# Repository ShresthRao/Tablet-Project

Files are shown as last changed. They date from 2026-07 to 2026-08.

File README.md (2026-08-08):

# Tablet Project
## Description
This project is a custom tablet. It contains a custom PCB and case. The PCB connects to a CM4 Lite Wireless module for processing and wireless connections. The PCB is connected to a Viekk VK1200 V2 device that is used as the digitiser, stylus and the display.

## Bill of Materials (BOM)

* Note: All prices are in USD (inclusive of GST where applicable). Production and assembly files contain additional specs where applicable.
* Note: Bom for Item 4: JLCPCB Custom Manufactured PCB is in /Production/assembly/Custom Tablet_bom_raw.csv, /Production/assembly/Custom Tablet_jlcpcb_bom.csv

### Purchased Components

| Item | Qty | Component | Price/1 Item (USD) | Link | Description |
| :---: | :---: | :--- | :---: | :--- | :--- |
| 1 | 2 | NOVA 9060100 8000mAh 3.7V Micro LiPo Battery Pack with PCB & 100mm Cable | $9.34 | [Robu.in](https://robu.in/product/nova-9060100-8000mah-3-7v-lipo-battery-pack/) | Lined in Parallel |
| 2 | 4 | Harwin R25-1001102 Hex Standoffs | $0.51 | [Element14](https://in.element14.com/harwin/r25-1001102/standoff-hex-f-f-brass-m2-5-11mm/dp/3754478) | Standoffs for CM4 module |
| 3 | 1 | Raspberry Pi Compute Module 4 | $110.16 | [Element14](https://in.element14.com/raspberry-pi/cm4104000/rpi-compute-module-4-lite-4gb/dp/3563487) | Compute module |
| 4 | 1 | JLCPCB Custom Manufactured PCB | $279.95 | [JLCPCB](https://cart.jlcpcb.com/quote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) | Custom PCB Ordered through JLCPCB |
| 5 | 1 | VEIKK VK1200 V2 Drawing Tablet | $157.65 | [Amazon](https://www.amazon.in/gp/product/B08G8CKSWK/) | Acts as the Screen, Digitiser and Stylus |
| 6 | 1 | Heat Shrink Tubing Kit (328 pcs) | $1.64 | [Robu.in](https://robu.in/product/328pcs-heat-shrink-tube-heat-shrink-tube-kit/) | Protection against short circuits |
| 7 | 1 | High-Temperature Kapton Polyimide Tape (10mm × 33m) | $1.03 | [Robu.in](https://robu.in/product/10mm-33m-100ft-high-temperature-heat-resistant-polyimide-kapton-tape-hot/) | Insulation |
| 8 | 1 | Digital Multimeter (Small LCD, AC/DC) | $1.80 | [Robu.in](https://robu.in/product/digital-multimeter-small-yellow-color-lcd-ac-dc-measuring-voltage-current/) | Tool to check for battery voltage and proper functionality |
| 9 | 1 | Multimeter Test Probes | $1.25 | [Robu.in](https://robu.in/product/1-month-warranty-1260/) | Probes for multimeter |
| Total | | | $575 (Adjusted for future price changes) | | |

### On-Hand Hardware & Tools

* Storage: Micro-SD card (64GB+)
* Cables: 3x USB-C cables, 1x Short HDMI cable
* Wiring: Red and Black battery wire
* Tools & Consumables: Soldering iron, flux, solder, tweezers, superglue
* Peripherals: USB keyboard and mouse

## Specifications
### Screen:
11.6 inch
Laminated anti-glare
8,192 levels of pressure sensitivity
Resolution is 1920 × 1080 pixels (Full HD)
Color Gamut: 72% NTSC

### PCB
1 HDMI port for connection of VIEKK VK1200 V2 device.
1 SD card slot
2 USB-C ports
2 Connectors for CM4 Lite Wireless module
1 Solder pads for connection of batteries

### Stylus
2 battery-less styluses
8,192 levels of pressure
60 degrees of tilt
290 RPS of report rate
5080 LPI of resolution

### Case (total size of custom tablet)
202 mm width
378 mm length
24 mm tall

### Software
Raspberry Pi OS (64-bit) with VIEKK drivers

## Screenshots of the design:
### Schematic
#### Full Screenshot
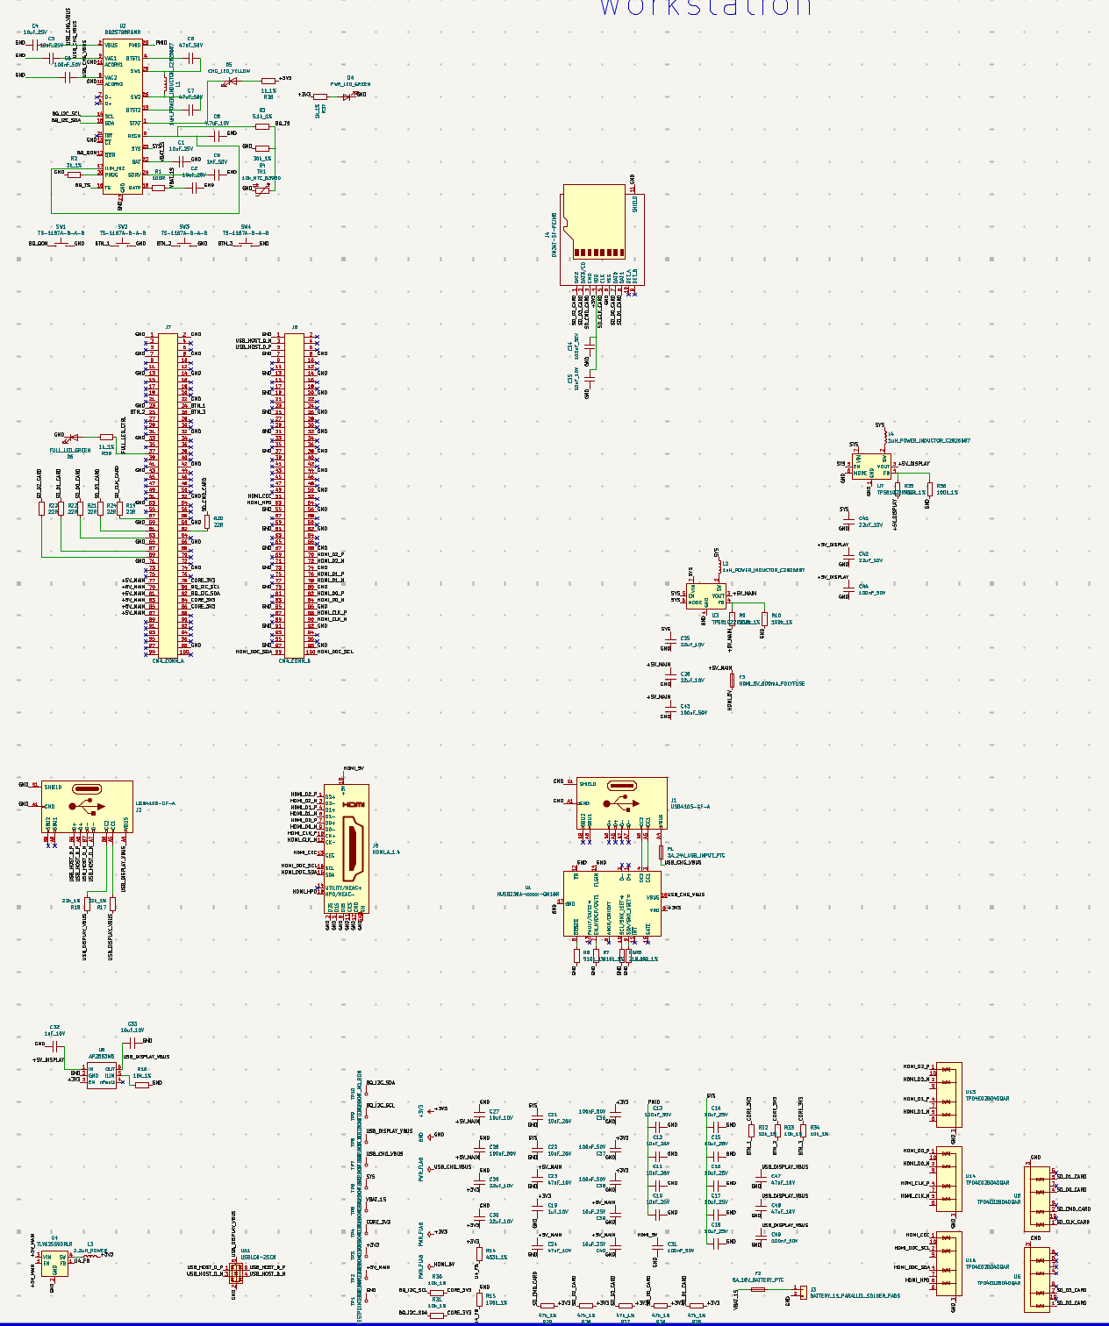
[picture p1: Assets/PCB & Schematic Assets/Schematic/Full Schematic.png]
Full Schematic Overview


#### Part-Wise screenshots
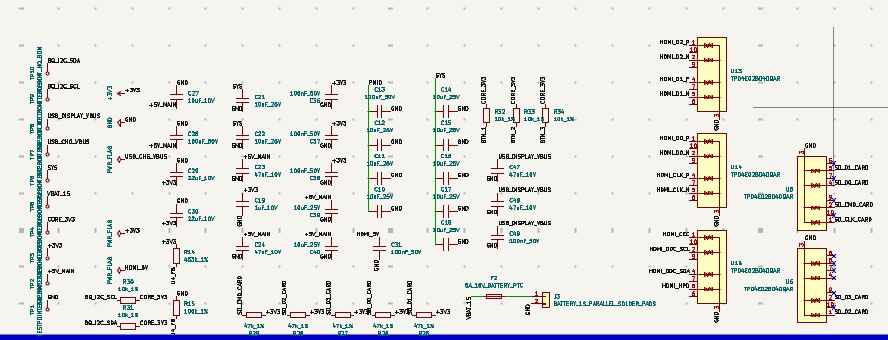
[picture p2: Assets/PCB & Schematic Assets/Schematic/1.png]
Schematic Page 1

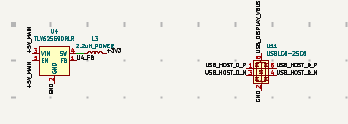
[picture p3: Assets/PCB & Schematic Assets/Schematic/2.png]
Schematic Page 2

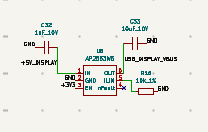
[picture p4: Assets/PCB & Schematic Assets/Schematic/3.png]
Schematic Page 3

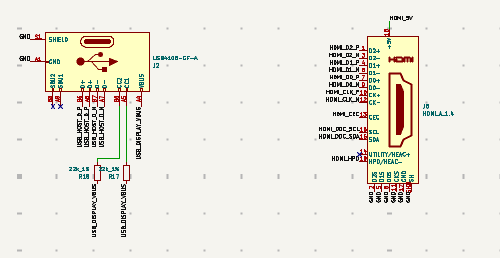
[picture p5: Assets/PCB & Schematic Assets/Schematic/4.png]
Schematic Page 4

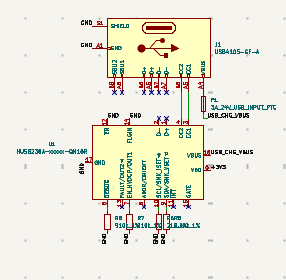
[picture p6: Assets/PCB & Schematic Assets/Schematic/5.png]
Schematic Page 5

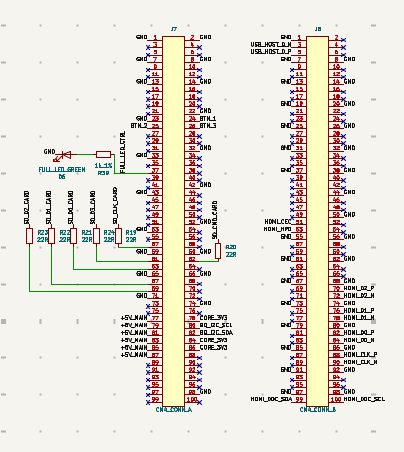
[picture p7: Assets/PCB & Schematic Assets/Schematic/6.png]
Schematic Page 6

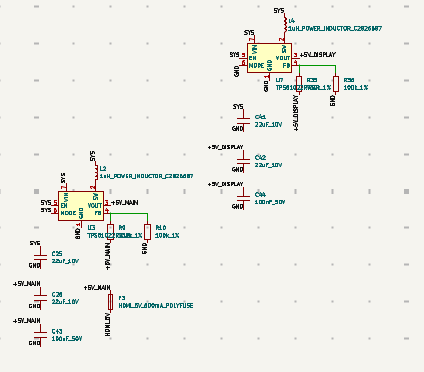
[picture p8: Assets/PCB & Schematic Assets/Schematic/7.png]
Schematic Page 7

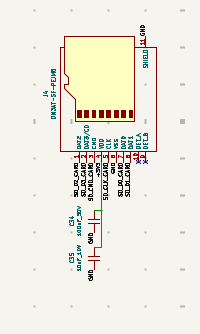
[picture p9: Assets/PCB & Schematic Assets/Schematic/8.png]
Schematic Page 8

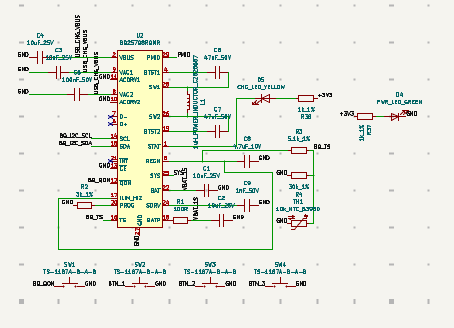
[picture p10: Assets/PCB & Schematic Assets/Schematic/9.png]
Schematic Page 9


### PCB
#### Zoned
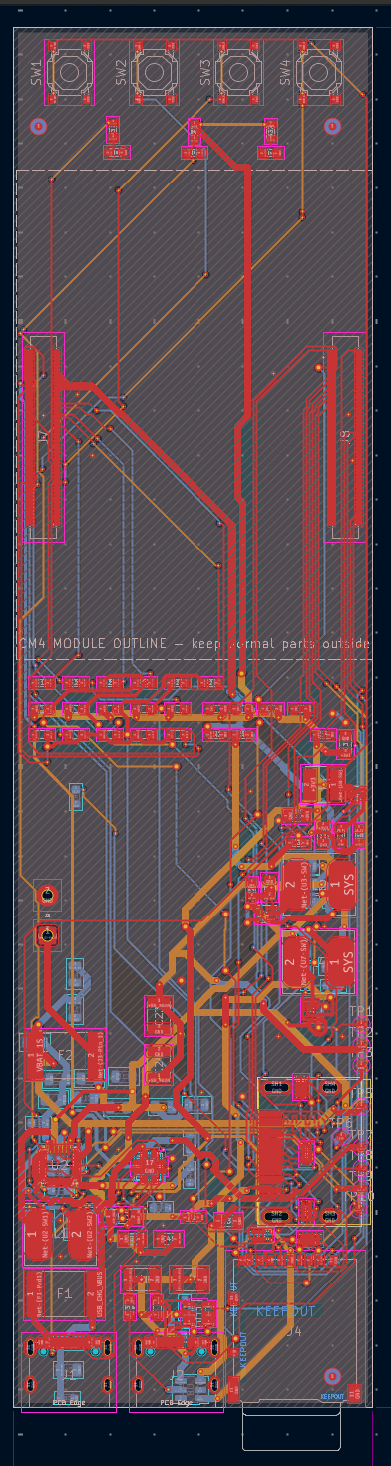
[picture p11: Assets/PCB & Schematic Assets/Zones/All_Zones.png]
All Layers With Zones

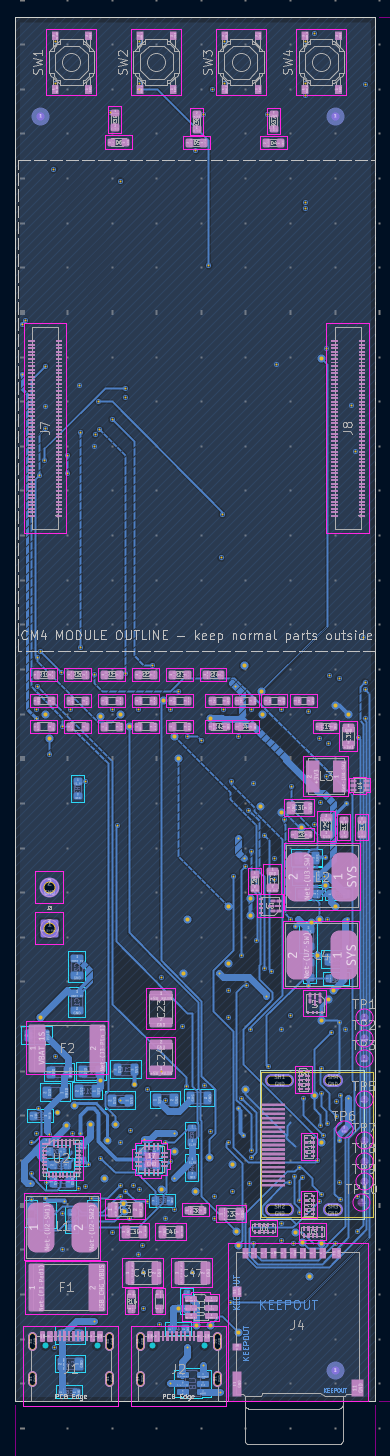
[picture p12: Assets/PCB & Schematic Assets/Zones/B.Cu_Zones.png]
Bottom Copper With Zones

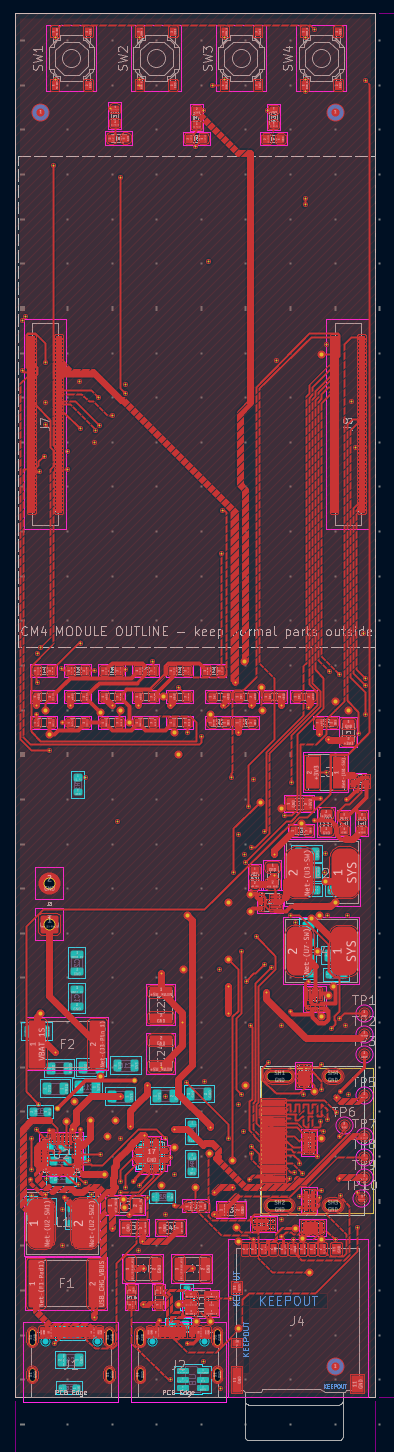
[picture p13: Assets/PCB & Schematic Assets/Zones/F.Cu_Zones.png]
Front Copper With Zones

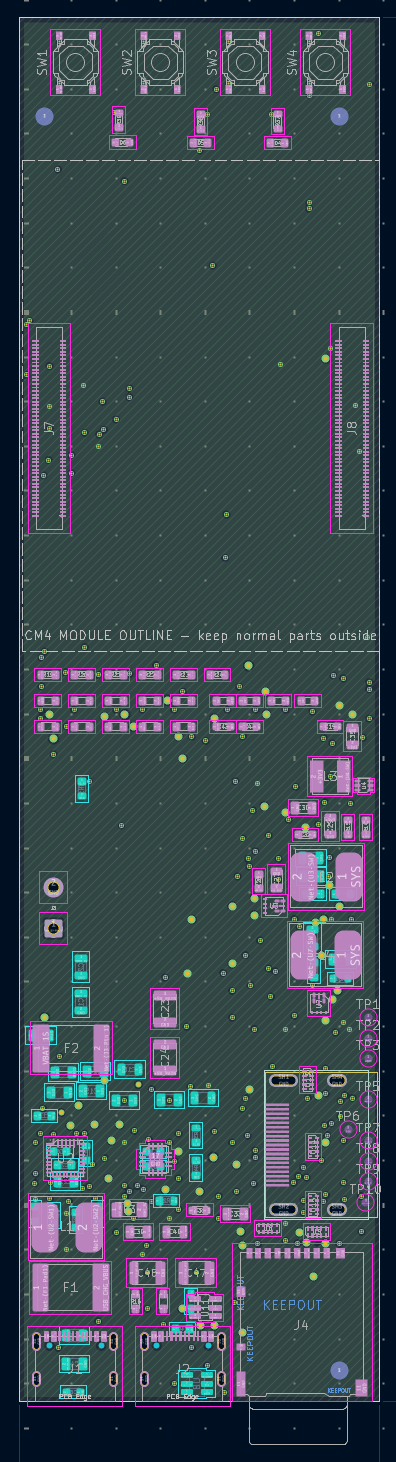
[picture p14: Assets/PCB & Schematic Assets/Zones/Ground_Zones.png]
Ground Copper With Zones

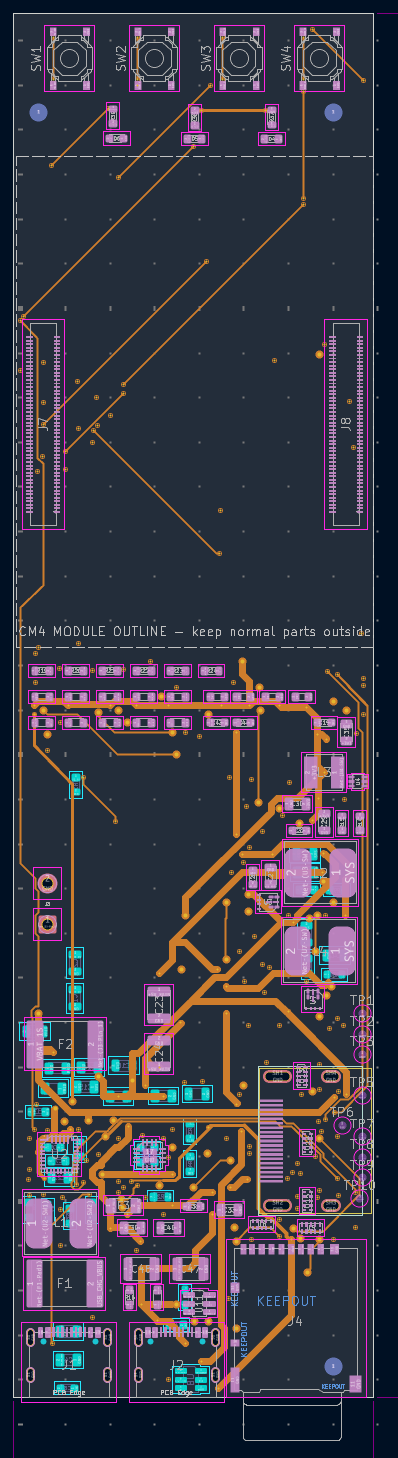
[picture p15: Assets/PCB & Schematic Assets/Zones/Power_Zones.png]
Power Copper With Zones


#### Un-Zoned
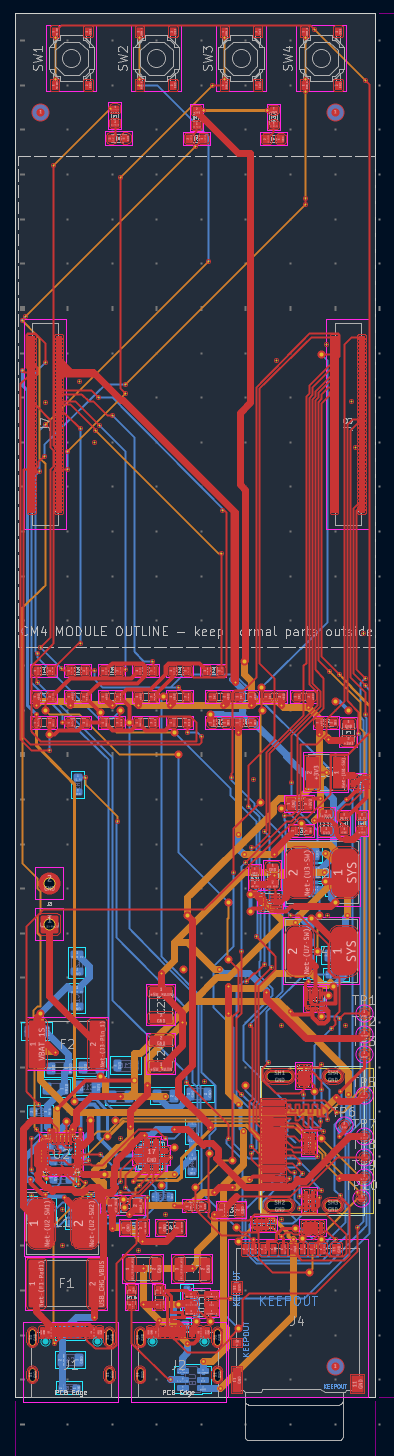
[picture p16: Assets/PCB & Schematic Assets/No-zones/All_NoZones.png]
All Layers No Zones

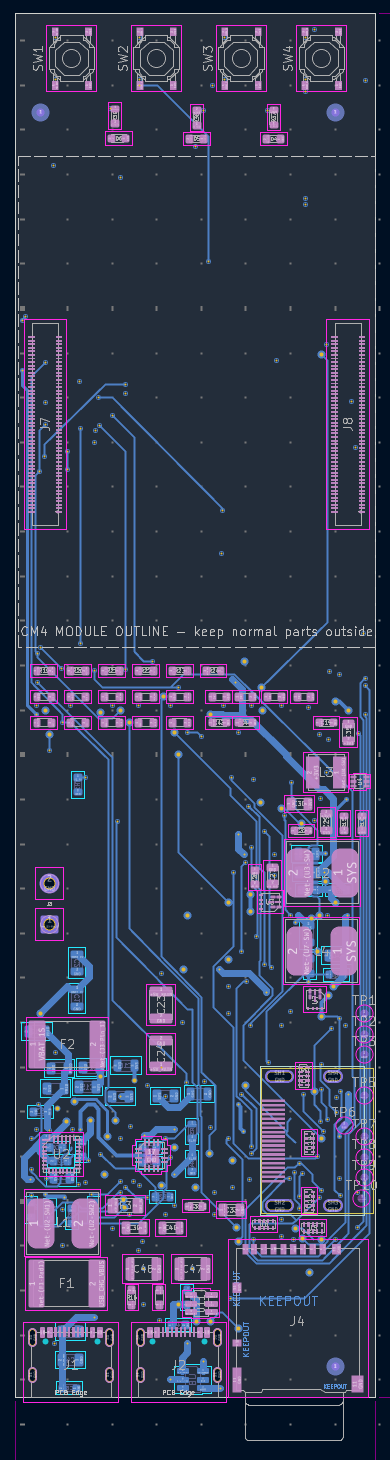
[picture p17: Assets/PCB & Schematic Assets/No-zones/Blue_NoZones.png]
Blue Layer No Zones

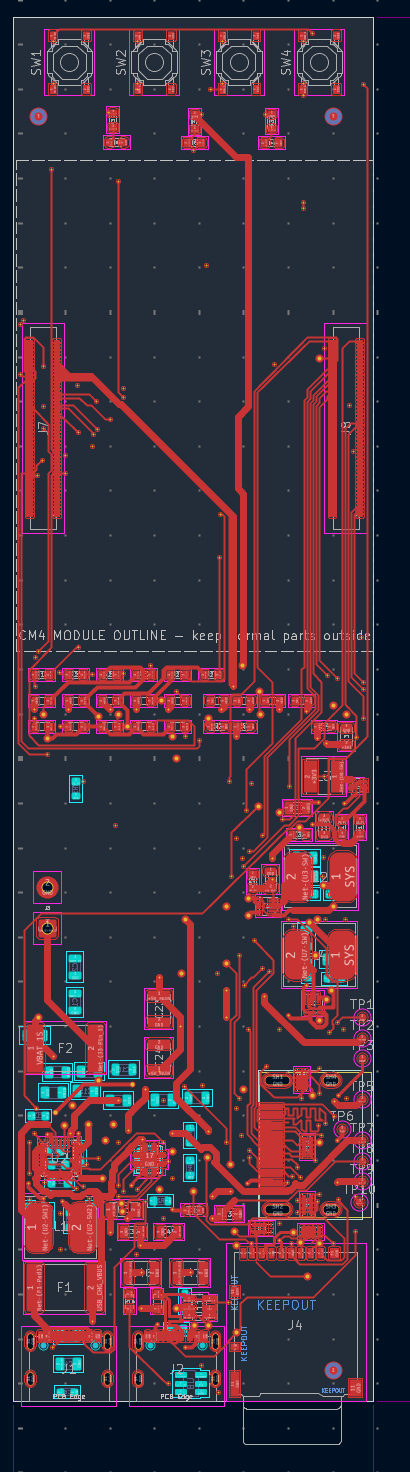
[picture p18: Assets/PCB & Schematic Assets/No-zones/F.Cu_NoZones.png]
Front Copper No Zones

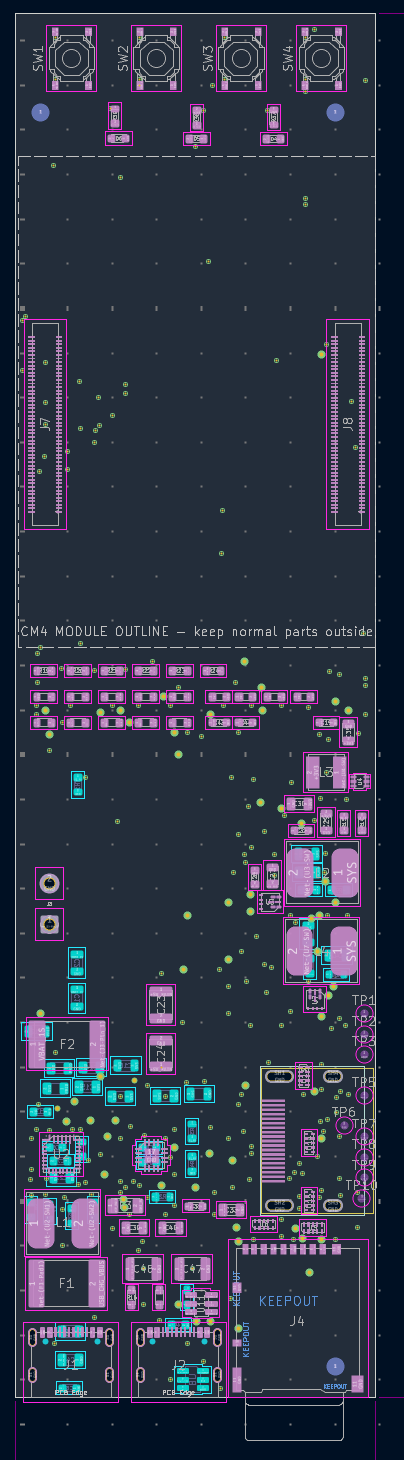
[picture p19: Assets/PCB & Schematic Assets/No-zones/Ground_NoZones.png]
Ground Layer No Zones

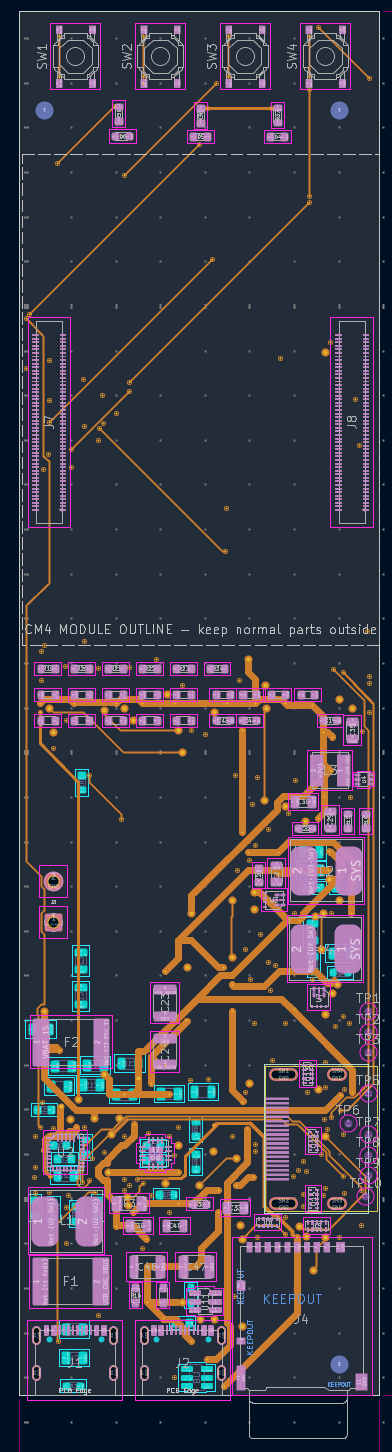
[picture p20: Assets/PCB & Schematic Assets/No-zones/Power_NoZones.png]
Power Layer No Zones


### CAD
#### Assembly
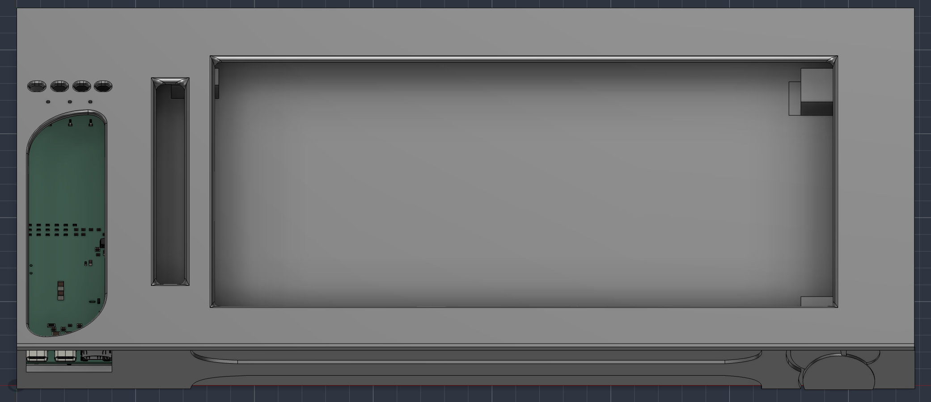
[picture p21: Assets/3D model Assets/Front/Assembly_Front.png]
Assembly Front View


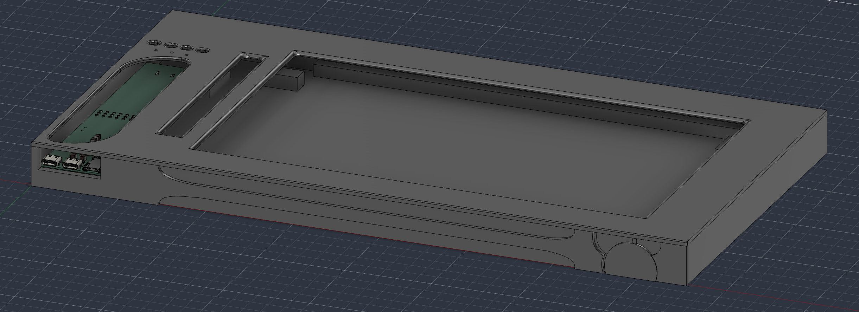
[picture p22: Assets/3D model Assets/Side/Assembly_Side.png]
Assembly Side View


#### Bottom Case
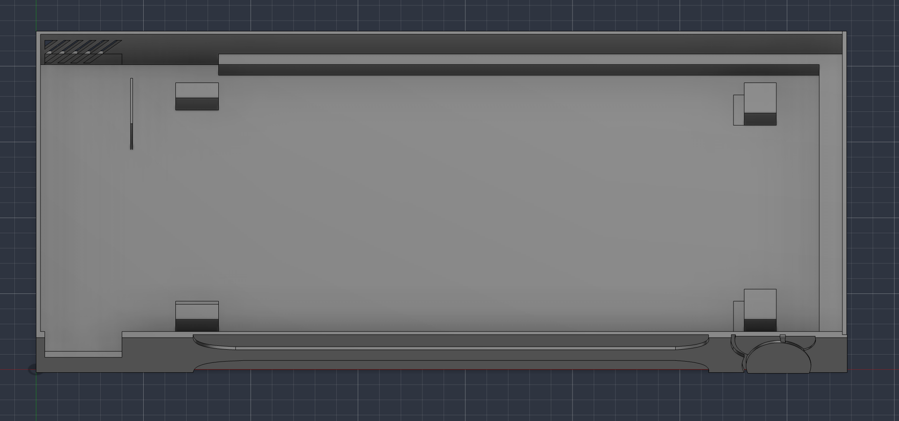
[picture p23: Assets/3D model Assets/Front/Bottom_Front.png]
Bottom Front View


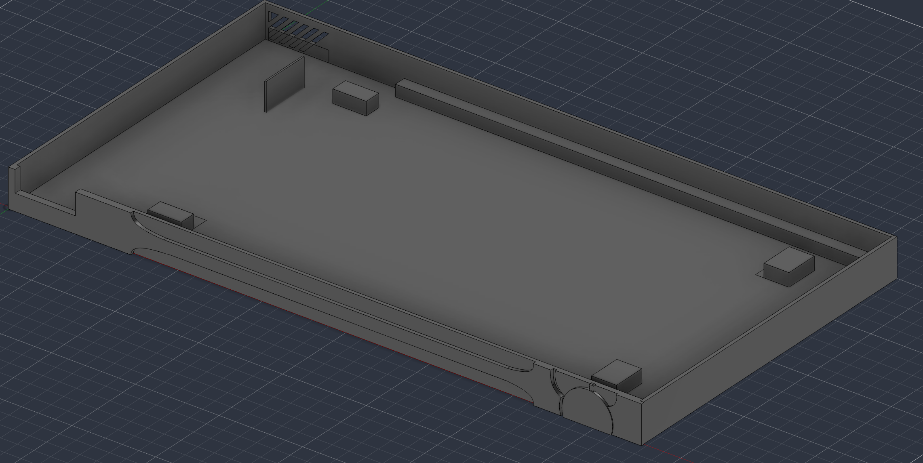
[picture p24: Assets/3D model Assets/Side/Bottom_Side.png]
Bottom Side View


#### Top Case
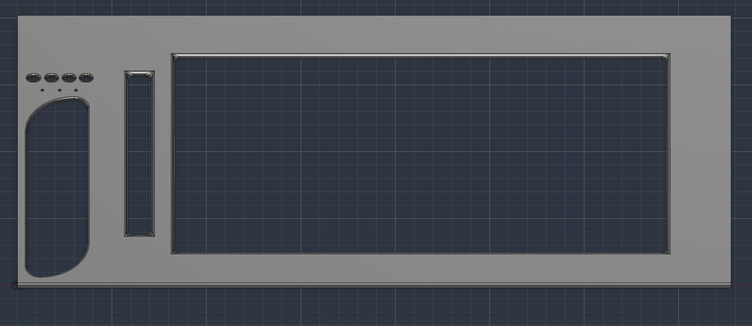
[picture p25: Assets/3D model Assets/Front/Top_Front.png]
Top Front View


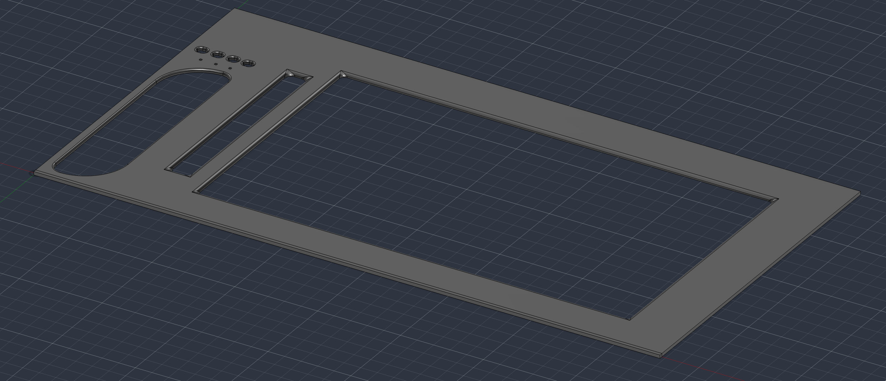
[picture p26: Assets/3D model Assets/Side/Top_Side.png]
Top Side View


****

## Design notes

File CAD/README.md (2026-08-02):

# CAD Files
## 3D print:stl files
These files are only for 3D printing, consisting of files for the top and bottom case. Any changes to source files would mean that these stl files need to be exported again.
## Assembly
These files are the assembly file in two formats (.f3z/.f3d and .step). It is a file consisting of the top case, bottom case and 3D PCB model all put together.
## Source files
### Bottom_Case
These files are the files related to the bottom case 3D model in two formats (.f3z and .step) and are used to edit the 3D model yourself.
### PCB_3D model
These files are the files related to the PCB 3D model in two formats (.f3z and .step) and are used to edit the 3D model yourself.
### Top_Case
These files are the files related to the top case 3D model in two formats (.f3z and .step) and are used to edit the 3D model yourself.

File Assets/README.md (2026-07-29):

# Asset Files
## 3D model files
### Front
These files are the screenshots of how the front view of the Assembly, Bottom Case and Top Case look.
### Side
These files are the screenshots of how the side view of the Assembly, Bottom Case and Top Case look.

## PCB & Schematic Assets
### No-Zones
These files are the screenshots of how all four planes individually look without any zones and how they look all together when combined.
### Schematic
These files are the screenshots of all components in the schematic.
### Zones
These files are the screenshots of how all four planes individually look with zones and how they look all together when combined.

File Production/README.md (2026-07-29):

# Production Files
## Assembly
This folder contains a file including all the positions of components on the PCB, in case any manufacturer requires such a file (Custom Tablet_positions.csv). 
It also includes the file used as a bill of materials for all the components JLCPCB will source (Custom Tablet_jlcpcb_bom.csv). 
It also contains a raw bill of materials file that is used for personal reference of all parts (not just JLCPCB sourced parts) (Custom Tablet_bom_raw.csv).
## Checks
This folder contains the final ERC and DRC checks to ensure that the PCB does not have any fatal errors before production. If PCB files are altered, they must be exported again.
## Gerbers
This folder contains all the files most manufacturers will need to manufacture the pcb. This includes drill files and all the other files necessary.

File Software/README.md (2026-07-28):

# Software:
## Steps:
### Download the Raspberry Pi OS (64-bit) model:

Link--> https://www.raspberrypi.com/software/operating-systems/

Scroll down to the Raspberry Pi OS (64-bit) and press download button next to "Raspberry Pi OS"

### Uploading the OS to tablet:

Download Raspberry Pi Imager

Attach SD card that is going to be used for the Tablet (Min 64gb)

Open app and select downloaded OS file and write to the attached SD card.

When finished, disconnect the SD card.

Then, connect the SD card to the Tablet and power on.

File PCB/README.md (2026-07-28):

# PCB Files
These are the files that are used to make your own changes to the PCB.
They are files for personal use, not for production

## Main files
Base files to open in KiCad

## Custom Libraries and 3D models
Files to import into KiCad as Footrprints and Symbols for specific parts of the PCB.

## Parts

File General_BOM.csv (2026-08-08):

Section | Item | Qty | Component | Price/1 Item (USD) | Link | Description
Note |  |  | All prices are in USD (inclusive of GST where applicable). Production and assembly files contain additional specs where applicable.
Note |  |  | Bom for Item 4: JLCPCB Custom Manufactured PCB is in /Production/assembly/Custom Tablet_bom_raw.csv, /Production/assembly/Custom Tablet_jlcpcb_bom.csv
Purchased Components | 1 | 2 | NOVA 9060100 8000mAh 3.7V Micro LiPo Battery Pack with PCB & 100mm Cable | $9.34 | https://robu.in/product/nova-9060100-8000mah-3-7v-lipo-battery-pack/ | Lined in Parallel
Purchased Components | 2 | 4 | Harwin R25-1001102 Hex Standoffs | $0.51 | https://in.element14.com/harwin/r25-1001102/standoff-hex-f-f-brass-m2-5-11mm/dp/3754478 | Standoffs for CM4 module
Purchased Components | 3 | 1 | Raspberry Pi Compute Module 4 | $110.16 | https://in.element14.com/raspberry-pi/cm4104000/rpi-compute-module-4-lite-4gb/dp/3563487 | Compute module
Purchased Components | 4 | 1 | JLCPCB Custom Manufactured PCB | $279.95 | https://cart.jlcpcb.com/quote | Custom PCB Ordered through JLCPCB
Purchased Components | 5 | 1 | VEIKK VK1200 V2 Drawing Tablet | $157.65 | https://www.amazon.in/gp/product/B08G8CKSWK/ | Acts as the Screen, Digitiser and Stylus
Purchased Components | 6 | 1 | Heat Shrink Tubing Kit (328 pcs) | $1.64 | https://robu.in/product/328pcs-heat-shrink-tube-heat-shrink-tube-kit/ | Protection against short circuits
Purchased Components | 7 | 1 | High-Temperature Kapton Polyimide Tape (10mm × 33m) | $1.03 | https://robu.in/product/10mm-33m-100ft-high-temperature-heat-resistant-polyimide-kapton-tape-hot/ | Insulation
Purchased Components | 8 | 1 | Digital Multimeter (Small LCD, AC/DC) | $1.80 | https://robu.in/product/digital-multimeter-small-yellow-color-lcd-ac-dc-measuring-voltage-current/ | Tool to check for battery voltage and proper functionality
Purchased Components | 9 | 1 | Multimeter Test Probes | $1.25 | https://robu.in/product/1-month-warranty-1260/ | Probes for multimeter
Purchased Components | Total |  |  | $575 (Adjusted for future price changes)
On-Hand Hardware & Tools |  |  | Storage: Micro-SD card (64GB+)
On-Hand Hardware & Tools |  |  | Cables: 3x USB-C cables, 1x Short HDMI cable
On-Hand Hardware & Tools |  |  | Wiring: Red and Black battery wire
On-Hand Hardware & Tools |  |  | Tools & Consumables: Soldering iron, flux, solder, tweezers, superglue
On-Hand Hardware & Tools |  |  | Peripherals: USB keyboard and mouse

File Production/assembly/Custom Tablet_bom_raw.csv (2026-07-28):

Designator | Comment | Footprint | LCSC | MPN | Manufacturer | Datasheet | Description | Quantity
C1 | 10uF_25V | Capacitor_SMD:C_0805_2012Metric | C15850 | CL21A106KAYNNNE | Samsung Electro-Mechanics |  | Unpolarized capacitor | 1
C2 | 10uF_25V | Capacitor_SMD:C_0805_2012Metric | C15850 | CL21A106KAYNNNE | Samsung Electro-Mechanics |  | Unpolarized capacitor | 1
C3 | 10uF_25V | Capacitor_SMD:C_0805_2012Metric | C15850 | CL21A106KAYNNNE | Samsung Electro-Mechanics |  | Unpolarized capacitor | 1
C4 | 10uF_25V | Capacitor_SMD:C_0805_2012Metric | C15850 | CL21A106KAYNNNE | Samsung Electro-Mechanics |  | Unpolarized capacitor | 1
C5 | 100nF_50V | Capacitor_SMD:C_0603_1608Metric | C14663 | CC0603KRX7R9BB104 | YAGEO |  | Unpolarized capacitor | 1
C6 | 47nF_50V | Capacitor_SMD:C_0603_1608Metric | C1622 | CL10B473KB8NNNC | Samsung Electro-Mechanics |  | Unpolarized capacitor | 1
C7 | 47nF_50V | Capacitor_SMD:C_0603_1608Metric | C1622 | CL10B473KB8NNNC | Samsung Electro-Mechanics |  | Unpolarized capacitor | 1
C8 | 4.7uF_10V | Capacitor_SMD:C_0603_1608Metric | C19666 | CL10A475KO8NNNC | Samsung Electro-Mechanics |  | Unpolarized capacitor | 1
C9 | 1nF_50V | Capacitor_SMD:C_0603_1608Metric | C1588 | CL10B102KB8NNNC | Samsung Electro-Mechanics |  | Unpolarized capacitor | 1
C10 | 10uF_25V | Capacitor_SMD:C_0805_2012Metric | C15850 | CL21A106KAYNNNE | Samsung Electro-Mechanics |  | Unpolarized capacitor | 1
C11 | 10uF_25V | Capacitor_SMD:C_0805_2012Metric | C15850 | CL21A106KAYNNNE | Samsung Electro-Mechanics |  | Unpolarized capacitor | 1
C12 | 10uF_25V | Capacitor_SMD:C_0805_2012Metric | C15850 | CL21A106KAYNNNE | Samsung Electro-Mechanics |  | Unpolarized capacitor | 1
C13 | 100nF_50V | Capacitor_SMD:C_0603_1608Metric | C14663 | CC0603KRX7R9BB104 | YAGEO |  | Unpolarized capacitor | 1
C14 | 10uF_25V | Capacitor_SMD:C_0805_2012Metric | C15850 | CL21A106KAYNNNE | Samsung Electro-Mechanics |  | Unpolarized capacitor | 1
C15 | 10uF_25V | Capacitor_SMD:C_0805_2012Metric | C15850 | CL21A106KAYNNNE | Samsung Electro-Mechanics |  | Unpolarized capacitor | 1
C16 | 10uF_25V | Capacitor_SMD:C_0805_2012Metric | C15850 | CL21A106KAYNNNE | Samsung Electro-Mechanics |  | Unpolarized capacitor | 1
C17 | 10uF_25V | Capacitor_SMD:C_0805_2012Metric | C15850 | CL21A106KAYNNNE | Samsung Electro-Mechanics |  | Unpolarized capacitor | 1
C18 | 10uF_25V | Capacitor_SMD:C_0805_2012Metric | C15850 | CL21A106KAYNNNE | Samsung Electro-Mechanics |  | Unpolarized capacitor | 1
C19 | 1uF_10V | Capacitor_SMD:C_0603_1608Metric | C15849 | CL10A105KB8NNNC | Samsung Electro-Mechanics |  | Unpolarized capacitor | 1
C21 | 10uF_25V | Capacitor_SMD:C_0805_2012Metric | C15850 | CL21A106KAYNNNE | Samsung Electro-Mechanics |  | Unpolarized capacitor | 1
C22 | 10uF_25V | Capacitor_SMD:C_0805_2012Metric | C15850 | CL21A106KAYNNNE | Samsung Electro-Mechanics |  | Unpolarized capacitor | 1
C23 | 47uF_10V | Capacitor_SMD:C_1210_3225Metric | C2932477 | CL32A476KOJNNNE | Samsung Electro-Mechanics |  | Unpolarized capacitor | 1
C24 | 47uF_10V | Capacitor_SMD:C_1210_3225Metric | C2932477 | CL32A476KOJNNNE | Samsung Electro-Mechanics |  | Unpolarized capacitor | 1
C25 | 22uF_10V | Capacitor_SMD:C_0805_2012Metric | C45783 | CL21A226MAQNNNE | Samsung Electro-Mechanics |  | Unpolarized capacitor | 1
C26 | 22uF_10V | Capacitor_SMD:C_0805_2012Metric | C45783 | CL21A226MAQNNNE | Samsung Electro-Mechanics |  | Unpolarized capacitor | 1
C27 | 10uF_10V | Capacitor_SMD:C_0805_2012Metric | C15850 | CL21A106KAYNNNE | Samsung Electro-Mechanics |  | Unpolarized capacitor | 1
C28 | 100nF_50V | Capacitor_SMD:C_0603_1608Metric | C14663 | CC0603KRX7R9BB104 | YAGEO |  | Unpolarized capacitor | 1
C29 | 22uF_10V | Capacitor_SMD:C_0805_2012Metric | C45783 | CL21A226MAQNNNE | Samsung Electro-Mechanics |  | Unpolarized capacitor | 1
C30 | 22uF_10V | Capacitor_SMD:C_0805_2012Metric | C45783 | CL21A226MAQNNNE | Samsung Electro-Mechanics |  | Unpolarized capacitor | 1
C31 | 100nF_50V | Capacitor_SMD:C_0603_1608Metric | C14663 | CC0603KRX7R9BB104 | YAGEO |  | Unpolarized capacitor | 1
C32 | 1uF_10V | Capacitor_SMD:C_0603_1608Metric | C15849 | CL10A105KB8NNNC | Samsung Electro-Mechanics |  | Unpolarized capacitor | 1
C33 | 10uF_10V | Capacitor_SMD:C_0805_2012Metric | C15850 | CL21A106KAYNNNE | Samsung Electro-Mechanics |  | Unpolarized capacitor | 1
C34 | 100nF_50V | Capacitor_SMD:C_0603_1608Metric | C14663 | CC0603KRX7R9BB104 | YAGEO |  | Unpolarized capacitor | 1
C35 | 10uF_10V | Capacitor_SMD:C_0805_2012Metric | C15850 | CL21A106KAYNNNE | Samsung Electro-Mechanics |  | Unpolarized capacitor | 1
C36 | 100nF_50V | Capacitor_SMD:C_0603_1608Metric | C14663 | CC0603KRX7R9BB104 | YAGEO |  | Unpolarized capacitor | 1
C37 | 100nF_50V | Capacitor_SMD:C_0603_1608Metric | C14663 | CC0603KRX7R9BB104 | YAGEO |  | Unpolarized capacitor | 1
C38 | 100nF_50V | Capacitor_SMD:C_0603_1608Metric | C14663 | CC0603KRX7R9BB104 | YAGEO |  | Unpolarized capacitor | 1
C39 | 10uF_25V | Capacitor_SMD:C_0805_2012Metric | C15850 | CL21A106KAYNNNE | Samsung Electro-Mechanics |  | Unpolarized capacitor | 1
C40 | 10uF_25V | Capacitor_SMD:C_0805_2012Metric | C15850 | CL21A106KAYNNNE | Samsung Electro-Mechanics |  | Unpolarized capacitor | 1
C41 | 22uF_10V | Capacitor_SMD:C_0805_2012Metric | C45783 | CL21A226MAQNNNE | Samsung Electro-Mechanics |  | Unpolarized capacitor | 1
C42 | 22uF_10V | Capacitor_SMD:C_0805_2012Metric | C45783 | CL21A226MAQNNNE | Samsung Electro-Mechanics |  | Unpolarized capacitor | 1
C43 | 100nF_50V | Capacitor_SMD:C_0603_1608Metric | C14663 | CC0603KRX7R9BB104 | YAGEO |  | Unpolarized capacitor | 1
C44 | 100nF_50V | Capacitor_SMD:C_0603_1608Metric | C14663 | CC0603KRX7R9BB104 | YAGEO |  | Unpolarized capacitor | 1
C47 | 47uF_10V | Capacitor_SMD:C_1210_3225Metric | C2932477 | CL32A476KOJNNNE | Samsung Electro-Mechanics |  | Unpolarized capacitor | 1
C48 | 47uF_10V | Capacitor_SMD:C_1210_3225Metric | C2932477 | CL32A476KOJNNNE | Samsung Electro-Mechanics |  | Unpolarized capacitor | 1
C49 | 100nF_50V | Capacitor_SMD:C_0603_1608Metric | C14663 | CC0603KRX7R9BB104 | YAGEO |  | Unpolarized capacitor | 1
D4 | PWR_LED_GREEN | LED_SMD:LED_0603_1608Metric | C7371903 | XL-1608UGC-06A | XINGLIGHT |  | Light emitting diode | 1
D5 | CHG_LED_YELLOW | LED_SMD:LED_0603_1608Metric | C965802 | XL-1608UYC-06 | XINGLIGHT |  | Light emitting diode | 1
D6 | FULL_LED_GREEN | LED_SMD:LED_0603_1608Metric | C7371903 | XL-1608UGC-06A | XINGLIGHT |  | Light emitting diode | 1
F1 | 3A_24V_USB_INPUT_PTC | Fuse:Fuse_2920_7451Metric | C2977527 | BSMD2920-300-24V | BHFUSE |  | Fuse | 1
F2 | 5A_16V_BATTERY_PTC | Fuse:Fuse_2920_7451Metric | C108585 | SMD2920P500TF/16 | PTTC(Polytronics Tech) |  | Fuse | 1
F3 | HDMI_5V_500mA_POLYFUSE | Fuse:Fuse_1206_3216Metric | C151162 | 1206L050/15YR | Littelfuse |  | Fuse | 1
J1 | USB4105-GF-A | Connector_USB:USB_C_Receptacle_GCT_USB4105-xx-A_16P_TopMnt_Horizontal | C3020560 | USB4105-GF-A | GCT | https://www.usb.org/sites/default/files/documents/usb_type-c.zip | USB 2.0-only 16P Type-C Receptacle connector | 1
J2 | USB4105-GF-A | Connector_USB:USB_C_Receptacle_GCT_USB4105-xx-A_16P_TopMnt_Horizontal | C3020560 | USB4105-GF-A | GCT | https://www.usb.org/sites/default/files/documents/usb_type-c.zip | USB 2.0-only 16P Type-C Receptacle connector | 1
J3 | BATTERY_1S_PARALLEL_SOLDER_PADS | Connector_Wire:SolderWire-0.5sqmm_1x02_P4.6mm_D0.9mm_OD2.1mm | N/A | 1S parallel battery wire solder pads | N/A |  | Generic connector, single row, 01x02, script generated (kicad-library-utils/schlib/autogen/connector/) | 1
J4 | DM3AT-SF-PEJM5 | Connector_Card:microSD_HC_Hirose_DM3AT-SF-PEJM5 | C114218 | DM3AT-SF-PEJM5 | Hirose | https://www.hirose.com/product/en/download_file/key_name/DM3/category/Catalog/doc_file_id/49662/?item_id=195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 | Micro SD Card Socket with card detection pins | 1
J6 | HDMI_A_1.4 | CM4IO:EDAC 690-019-298-412 | C5291558 | 690-019-298-412 | EDAC | https://en.wikipedia.org/wiki/HDMI | HDMI 1.4+ type A connector | 1
J7 | CM4_CONN_A | Connector_Hirose_DF40:Hirose_DF40C-100DS-0.4V_2x50_P0.4mm | C597931 | DF40C-100DS-0.4V(51) | Hirose / HRS | https://datasheets.raspberrypi.com/cm4/cm4-datasheet.pdf | Raspberry Pi CM4 board-to-board connector A using Hirose DF40C-100DS-0.4V | 1
J8 | CM4_CONN_B | Connector_Hirose_DF40:Hirose_DF40C-100DS-0.4V_2x50_P0.4mm | C597931 | DF40C-100DS-0.4V(51) | Hirose / HRS | https://datasheets.raspberrypi.com/cm4/cm4-datasheet.pdf | Raspberry Pi CM4 board-to-board connector B using Hirose DF40C-100DS-0.4V | 1
L1 | 1uH_POWER_INDUCTOR_C2826687 | Inductor_SMD:L_Sumida_CR75 | C2826687 | CD75-1R0M | Cenker / CD75 series |  | Inductor | 1
L2 | 1uH_POWER_INDUCTOR_C2826687 | Inductor_SMD:L_Sumida_CR75 | C2826687 | CD75-1R0M | Cenker / CD75 series |  | Inductor | 1
L3 | 2.2uH_POWER | Inductor_SMD:L_Bourns-SRN4018 | C2044386 | SRN4018TA-2R2M | Bourns |  | Inductor | 1
L4 | 1uH_POWER_INDUCTOR_C2826687 | Inductor_SMD:L_Sumida_CR75 | C2826687 | CD75-1R0M | Cenker / CD75 series |  | Inductor | 1
R1 | 100R | Resistor_SMD:R_0603_1608Metric | C22775 | 0603 100R 1% | UNI-ROYAL / Generic |  | Resistor | 1
R2 | 3k_1% | Resistor_SMD:R_0603_1608Metric | C4211 | 0603WAF3001T5E | UNI-ROYAL |  | Resistor | 1
R3 | 5.1k_1% | Resistor_SMD:R_0603_1608Metric | C23186 | 5.1k 1% 0603 | UNI-ROYAL / Generic |  | Resistor | 1
R4 | 30k_1% | Resistor_SMD:R_0603_1608Metric | C22984 | 0603WAF3002T5E | UNI-ROYAL |  | Resistor | 1
R5 | 6.04k_1% | Resistor_SMD:R_0603_1608Metric | C25977 | 0603WAF6041T5E | UNI-ROYAL |  | Resistor | 1
R6 | 21k_1% | Resistor_SMD:R_0603_1608Metric | C22956 | 0603WAF2102T5E | UNI-ROYAL |  | Resistor | 1
R7 | 910k_1% | Resistor_SMD:R_0603_1608Metric | C137672 | RC0603FR-07910KL | YAGEO |  | Resistor | 1
R8 | 910k_1% | Resistor_SMD:R_0603_1608Metric | C137672 | RC0603FR-07910KL | YAGEO |  | Resistor | 1
R9 | 732k_1% | Resistor_SMD:R_0603_1608Metric | C23239 | 0603WAF7323T5E | UNI-ROYAL |  | Resistor | 1
R10 | 100k_1% | Resistor_SMD:R_0603_1608Metric | C25803 | 0603WAF1003T5E | UNI-ROYAL |  | Resistor | 1
R14 | 453k_1% | Resistor_SMD:R_0603_1608Metric | C273765 | RC0603FR-07453KL | YAGEO |  | Resistor | 1
R15 | 100k_1% | Resistor_SMD:R_0603_1608Metric | C25803 | 0603WAF1003T5E | UNI-ROYAL |  | Resistor | 1
R16 | 10k_1% | Resistor_SMD:R_0603_1608Metric | C25804 | 0603WAF1002T5E | UNI-ROYAL |  | Resistor | 1
R17 | 22k_1% | Resistor_SMD:R_0603_1608Metric | C31850 | 0603WAF2202T5E | UNI-ROYAL |  | Resistor | 1
R18 | 22k_1% | Resistor_SMD:R_0603_1608Metric | C31850 | 0603WAF2202T5E | UNI-ROYAL |  | Resistor | 1
R19 | 22R | Resistor_SMD:R_0603_1608Metric | C23345 | 0603WAF220JT5E | UNI-ROYAL |  | Resistor | 1
R20 | 22R | Resistor_SMD:R_0603_1608Metric | C23345 | 0603WAF220JT5E | UNI-ROYAL |  | Resistor | 1
R21 | 22R | Resistor_SMD:R_0603_1608Metric | C23345 | 0603WAF220JT5E | UNI-ROYAL |  | Resistor | 1
R22 | 22R | Resistor_SMD:R_0603_1608Metric | C23345 | 0603WAF220JT5E | UNI-ROYAL |  | Resistor | 1
R23 | 22R | Resistor_SMD:R_0603_1608Metric | C23345 | 0603WAF220JT5E | UNI-ROYAL |  | Resistor | 1
R24 | 22R | Resistor_SMD:R_0603_1608Metric | C23345 | 0603WAF220JT5E | UNI-ROYAL |  | Resistor | 1
R25 | 47k_1% | Resistor_SMD:R_0603_1608Metric | C25819 | 0603WAF4702T5E | UNI-ROYAL |  | Resistor | 1
R26 | 47k_1% | Resistor_SMD:R_0603_1608Metric | C25819 | 0603WAF4702T5E | UNI-ROYAL |  | Resistor | 1
R27 | 47k_1% | Resistor_SMD:R_0603_1608Metric | C25819 | 0603WAF4702T5E | UNI-ROYAL |  | Resistor | 1
R28 | 47k_1% | Resistor_SMD:R_0603_1608Metric | C25819 | 0603WAF4702T5E | UNI-ROYAL |  | Resistor | 1
R29 | 47k_1% | Resistor_SMD:R_0603_1608Metric | C25819 | 0603WAF4702T5E | UNI-ROYAL |  | Resistor | 1
R30 | 10k_1% | Resistor_SMD:R_0603_1608Metric | C25804 | 0603WAF1002T5E | UNI-ROYAL |  | Resistor | 1
R31 | 10k_1% | Resistor_SMD:R_0603_1608Metric | C25804 | 0603WAF1002T5E | UNI-ROYAL |  | Resistor | 1
R32 | 10k_1% | Resistor_SMD:R_0603_1608Metric | C25804 | 0603WAF1002T5E | UNI-ROYAL |  | Resistor | 1
R33 | 10k_1% | Resistor_SMD:R_0603_1608Metric | C25804 | 0603WAF1002T5E | UNI-ROYAL |  | Resistor | 1
R34 | 10k_1% | Resistor_SMD:R_0603_1608Metric | C25804 | 0603WAF1002T5E | UNI-ROYAL |  | Resistor | 1
R35 | 732k_1% | Resistor_SMD:R_0603_1608Metric | C23239 | 0603WAF7323T5E | UNI-ROYAL |  | Resistor | 1
R36 | 100k_1% | Resistor_SMD:R_0603_1608Metric | C25803 | 0603WAF1003T5E | UNI-ROYAL |  | Resistor | 1
R37 | 1k_1% | Resistor_SMD:R_0603_1608Metric | C21190 | 0603WAF1001T5E | UNI-ROYAL |  | Resistor | 1
R38 | 1k_1% | Resistor_SMD:R_0603_1608Metric | C21190 | 0603WAF1001T5E | UNI-ROYAL |  | Resistor | 1
R39 | 1k_1% | Resistor_SMD:R_0603_1608Metric | C21190 | 0603WAF1001T5E | UNI-ROYAL |  | Resistor | 1
SW1 | TS-1187A-B-A-B | Button_Switch_SMD:SW_Push_1P1T_XKB_TS-1187A | C318884 | TS-1187A-B-A-B | XKB Connectivity |  | Push button switch, generic, two pins | 1
SW2 | TS-1187A-B-A-B | Button_Switch_SMD:SW_Push_1P1T_XKB_TS-1187A | C318884 | TS-1187A-B-A-B | XKB Connectivity |  | Push button switch, generic, two pins | 1
SW3 | TS-1187A-B-A-B | Button_Switch_SMD:SW_Push_1P1T_XKB_TS-1187A | C318884 | TS-1187A-B-A-B | XKB Connectivity |  | Push button switch, generic, two pins | 1
SW4 | TS-1187A-B-A-B | Button_Switch_SMD:SW_Push_1P1T_XKB_TS-1187A | C318884 | TS-1187A-B-A-B | XKB Connectivity |  | Push button switch, generic, two pins | 1
TH1 | 10k_NTC_B3950 | Resistor_SMD:R_0603_1608Metric | C2892547 | 10k NTC B3950 | Generic |  | Temperature dependent resistor, negative temperature coefficient | 1
U1 | HUSB238A-xxxxx-QN16R | Package_DFN_QFN:WQFN-16-1EP_3x3mm_P0.5mm_EP1.75x1.75mm | C24833806 | HUSB238A-BB001-QN16R | Hynetek | https://www.lcsc.com/datasheet/lcsc_datasheet_2412301710_Hynetek-HUSB238A-BB001-QN16R_C24833806.pdf | USB-PD Sink IC Port Controller, VBUS = 3..48V, USB Type-C rev. 2.1, USB-PD rev. 3.1, BC1.2, QC2.0, WQFN-16 | 1
U2 | BQ25798RQMR | Package_DFN_QFN:Texas_RQM0029A_VQFN-29_4x4mm_P0.4mm | C2876593 | BQ25798RQMR | Texas Instruments | https://www.ti.com/lit/ds/symlink/bq25798.pdf | I2C controlled, 5A Buck-Boost battery charger (1-4 cell, Li-Ion / Li-Polymer), USB BC1.2 / HVDCP detection, 3.6..24V VBUS, 3..18.8V charge voltage regulation, 0.75..1.5 MHz, VQFN-29 (Texas RQM0029A) | 1
U3 | TPS61022RWUR | Package_DFN_QFN:Texas_RWU0007A_VQFN-7_2x2mm_P0.5mm | C915088 | TPS61022RWUR | Texas Instruments | https://www.ti.com/lit/ds/symlink/tps61022.pdf | 8A Boost Converter, 0.5-5.5 V input, 2.2-5.5V output, Texas RWU0007A VQFN-7 | 1
U4 | TLV62569DRLR | Package_TO_SOT_SMD:SOT-563 | C163217 | TLV62569DRLR | Texas Instruments | http://www.ti.com/lit/ds/symlink/tlv62569.pdf | High Efficiency Synchronous Buck Converter, Adjustable Output 0.6V-5.5V, 2A, SOT-563-6 | 1
U5 | TPD4E02B04DQAR | Package_SON:USON-10_2.5x1.0mm_P0.5mm | C106794 | TPD4E02B04DQAR | Texas Instruments | http://www.ti.com/lit/ds/symlink/tpd4e02b04.pdf | 4-Channel ESD Protection Diode for USB Type-C and HDMI 2.0, USON-10 | 1
U6 | TPD4E02B04DQAR | Package_SON:USON-10_2.5x1.0mm_P0.5mm | C106794 | TPD4E02B04DQAR | Texas Instruments | http://www.ti.com/lit/ds/symlink/tpd4e02b04.pdf | 4-Channel ESD Protection Diode for USB Type-C and HDMI 2.0, USON-10 | 1
U7 | TPS61022RWUR | Package_DFN_QFN:Texas_RWU0007A_VQFN-7_2x2mm_P0.5mm | C915088 | TPS61022RWUR | Texas Instruments | https://www.ti.com/lit/ds/symlink/tps61022.pdf | 8A Boost Converter, 0.5-5.5 V input, 2.2-5.5V output, Texas RWU0007A VQFN-7 | 1
U8 | AP2553W6 | Package_TO_SOT_SMD:SOT-23-6 | C212302 | AP2553W6-7 | Diodes Incorporated | https://www.diodes.com/assets/Datasheets/AP255x.pdf |  | 1
U11 | USBLC6-2SC6 | Package_TO_SOT_SMD:SOT-23-6 | C7519 | USBLC6-2SC6 | STMicroelectronics | https://www.st.com/resource/en/datasheet/usblc6-2.pdf | Very low capacitance ESD protection diode, 2 data-line, SOT-23-6 | 1
U13 | TPD4E02B04DQAR | Package_SON:USON-10_2.5x1.0mm_P0.5mm | C106794 | TPD4E02B04DQAR | Texas Instruments | http://www.ti.com/lit/ds/symlink/tpd4e02b04.pdf | 4-Channel ESD Protection Diode for USB Type-C and HDMI 2.0, USON-10 | 1
U14 | TPD4E02B04DQAR | Package_SON:USON-10_2.5x1.0mm_P0.5mm | C106794 | TPD4E02B04DQAR | Texas Instruments | http://www.ti.com/lit/ds/symlink/tpd4e02b04.pdf | 4-Channel ESD Protection Diode for USB Type-C and HDMI 2.0, USON-10 | 1
U15 | TPD4E02B04DQAR | Package_SON:USON-10_2.5x1.0mm_P0.5mm | C106794 | TPD4E02B04DQAR | Texas Instruments | http://www.ti.com/lit/ds/symlink/tpd4e02b04.pdf | 4-Channel ESD Protection Diode for USB Type-C and HDMI 2.0, USON-10 | 1

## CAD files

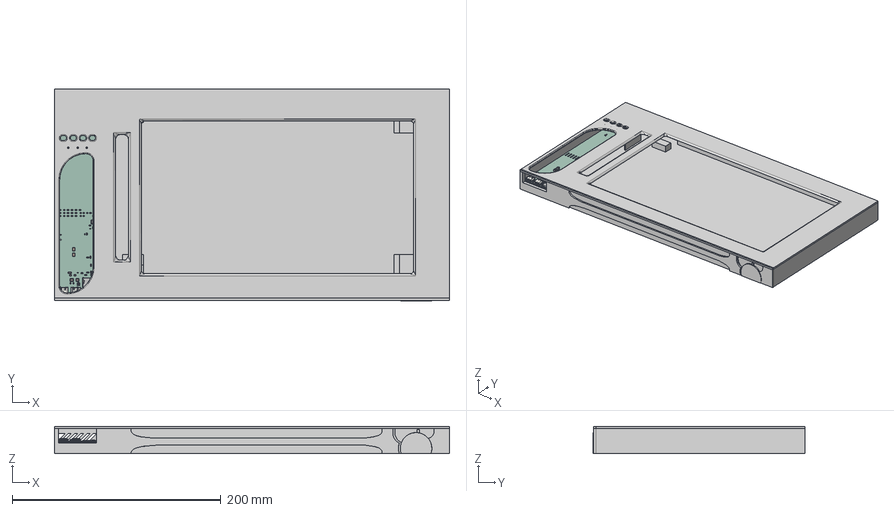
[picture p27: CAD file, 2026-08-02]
CAD/Assembly/Tablet Project Assembly.step
378.0 x 202.5 x 26.0 mm
SOT_563
C_0603_1608Metric_1 x 17
SOT-23-6_1 x 2
R_0603_1608Metric_1 x 37
L_Bourns-SRN4018_1
C_1210_3225Metric_1 x 4
Fuse_1206_3216Metric_1
C_0805_2012Metric_1 x 25
LED_0603_1608Metric_1 x 3
USON_10_25x10mm_Pitch05mm x 5
USB_C_Receptacle_16P_TopMnt_Horizontal_GCT_USB4105-xx-A x 2
microSD_HC_Hirose_DM3AT-SF-PEJM5_1
Custom Tablet_PCB

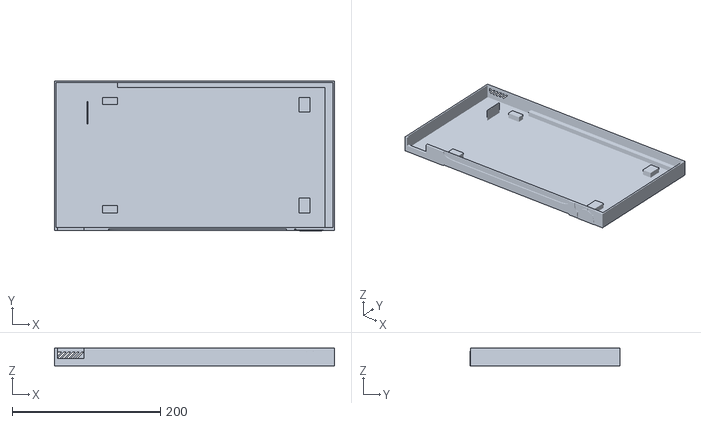
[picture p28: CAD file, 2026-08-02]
CAD/3D print:stl files/Tablet Project_Bottom Case.stl
378.0 x 202.5 x 24.0

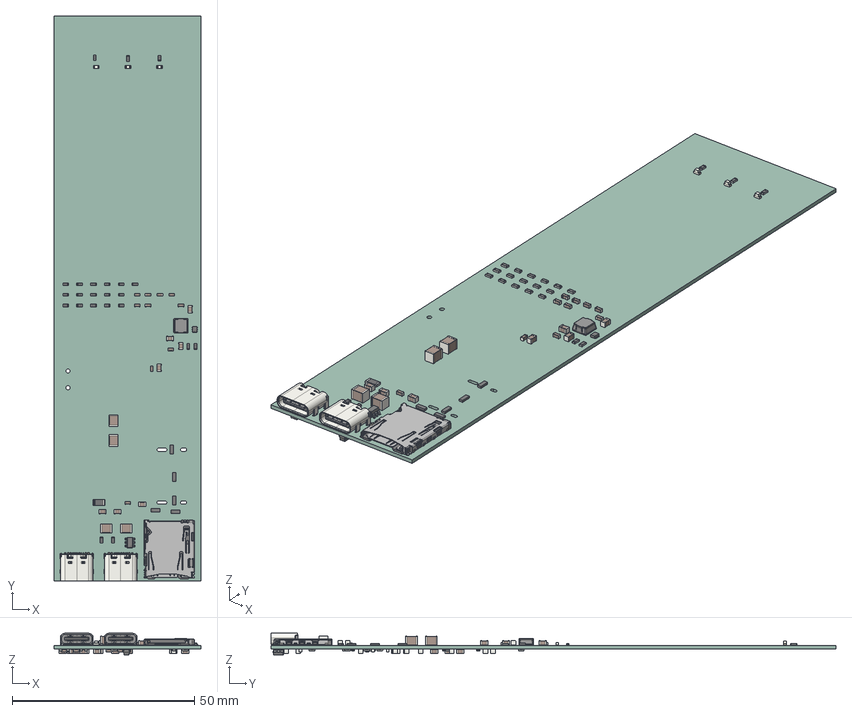
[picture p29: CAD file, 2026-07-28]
CAD/Source Files/PCB_3D Model/Tablet_Project_PCB.step
40.3 x 155.0 x 5.94 mm
SOT_563
C_0603_1608Metric_1 x 17
SOT-23-6_1 x 2
R_0603_1608Metric_1 x 37
L_Bourns-SRN4018_1
C_1210_3225Metric_1 x 4
Fuse_1206_3216Metric_1
C_0805_2012Metric_1 x 25
LED_0603_1608Metric_1 x 3
USON_10_25x10mm_Pitch05mm x 5
USB_C_Receptacle_16P_TopMnt_Horizontal_GCT_USB4105-xx-A x 2
microSD_HC_Hirose_DM3AT-SF-PEJM5_1
Custom Tablet_PCB

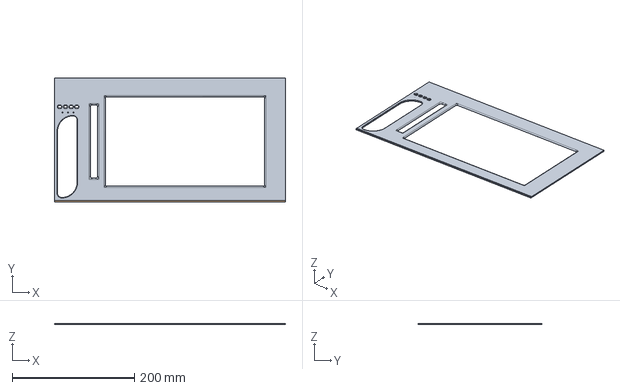
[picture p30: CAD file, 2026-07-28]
CAD/Source Files/Top_Case/Tablet_Project_Top_Case.step
377.8 x 202.0 x 2.00 mm

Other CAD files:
CAD/Source Files/Bottom_Case/Tablet Project_Bottom Case.step
CAD/3D print:stl files/Tablet_Project_Top_Case.stl
CAD/Assembly/Tablet Project Assembly.f3z
CAD/Source Files/Bottom_Case/Tablet Project_Bottom Case.f3d
CAD/Source Files/PCB_3D Model/Tablet_Project_PCB.f3d
CAD/Source Files/Top_Case/Tablet_Project_Top_Case.f3d

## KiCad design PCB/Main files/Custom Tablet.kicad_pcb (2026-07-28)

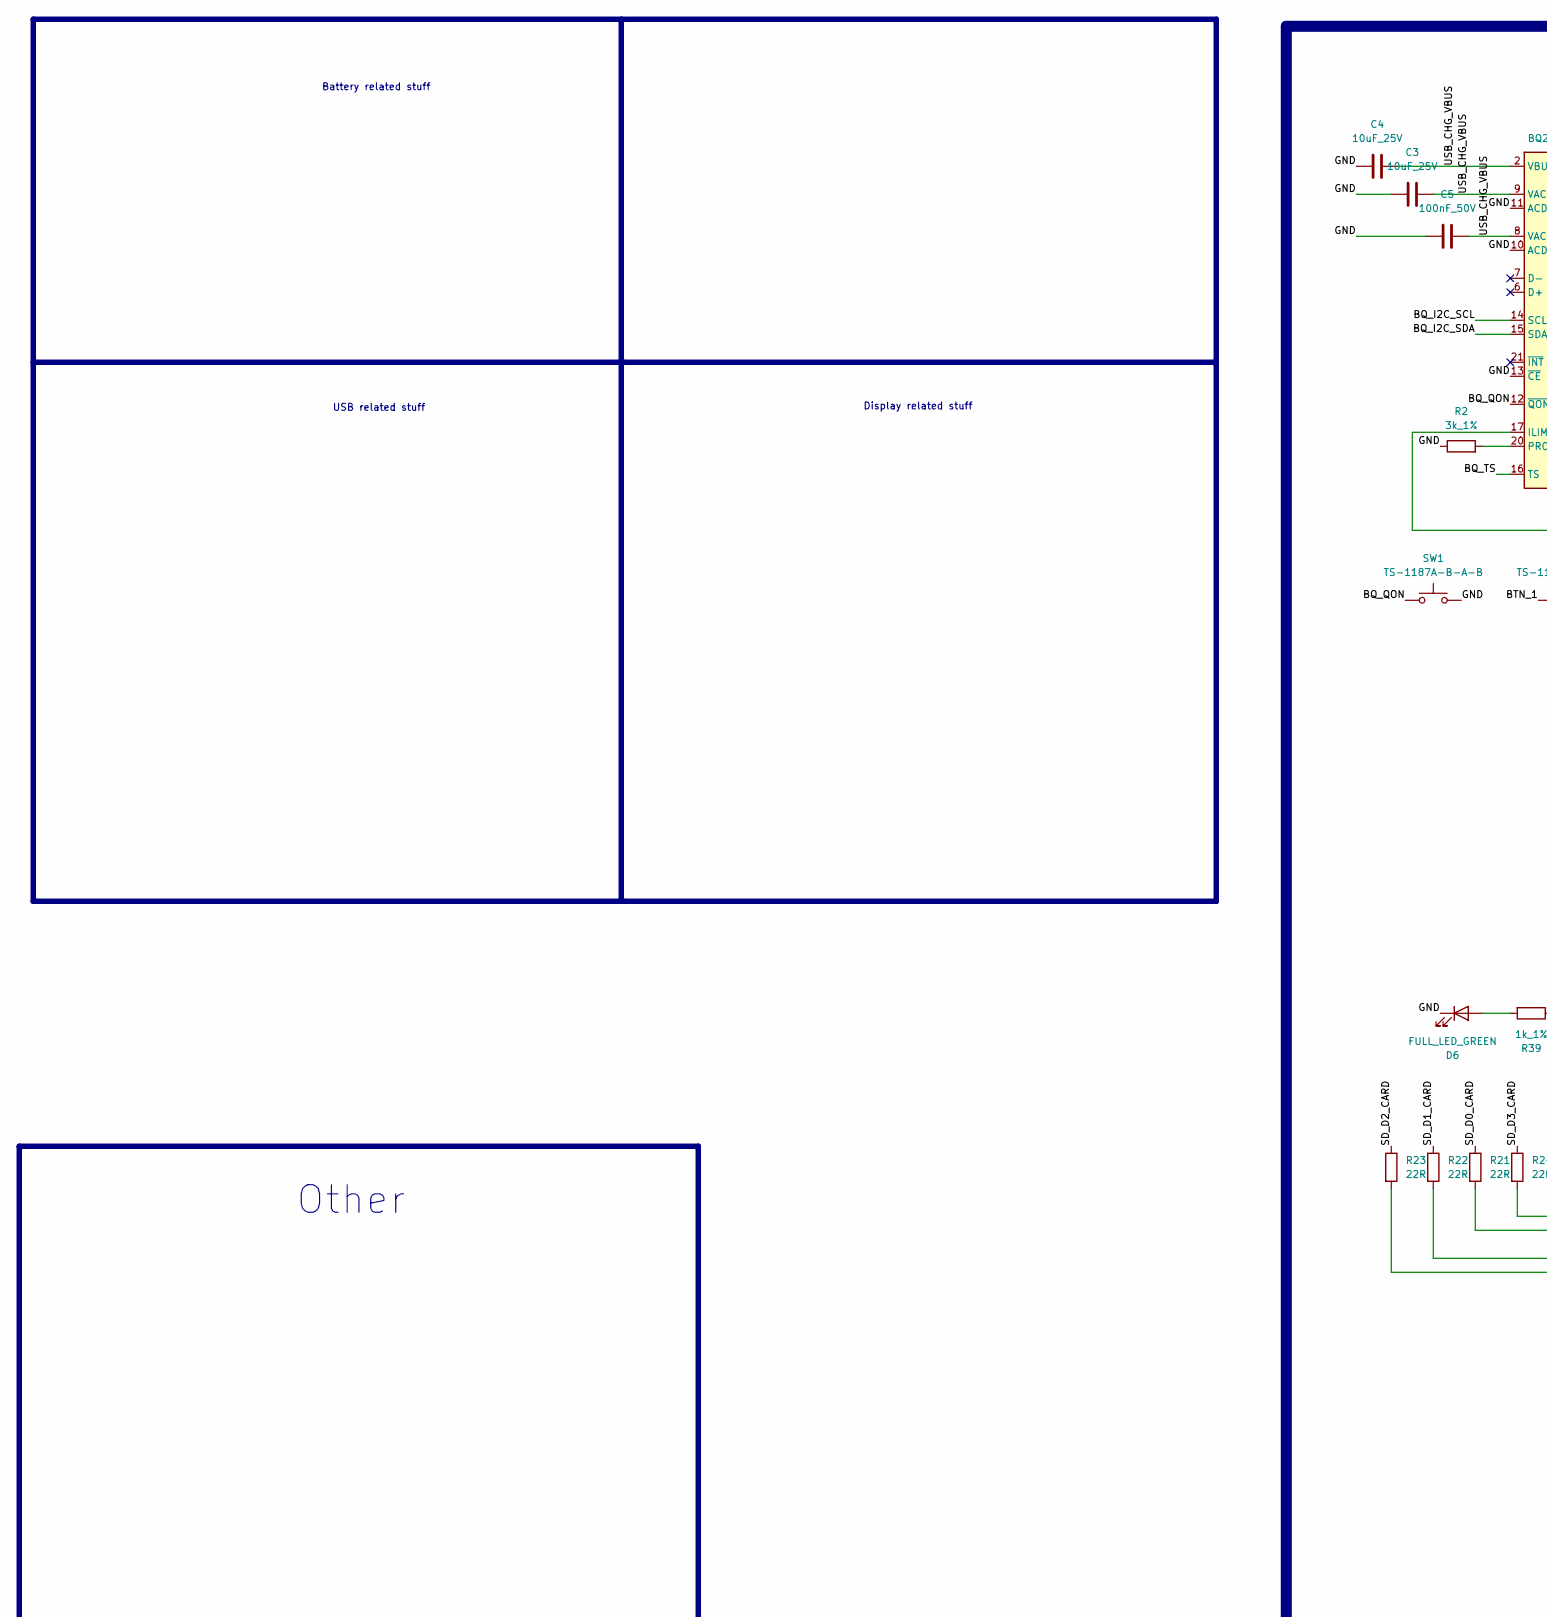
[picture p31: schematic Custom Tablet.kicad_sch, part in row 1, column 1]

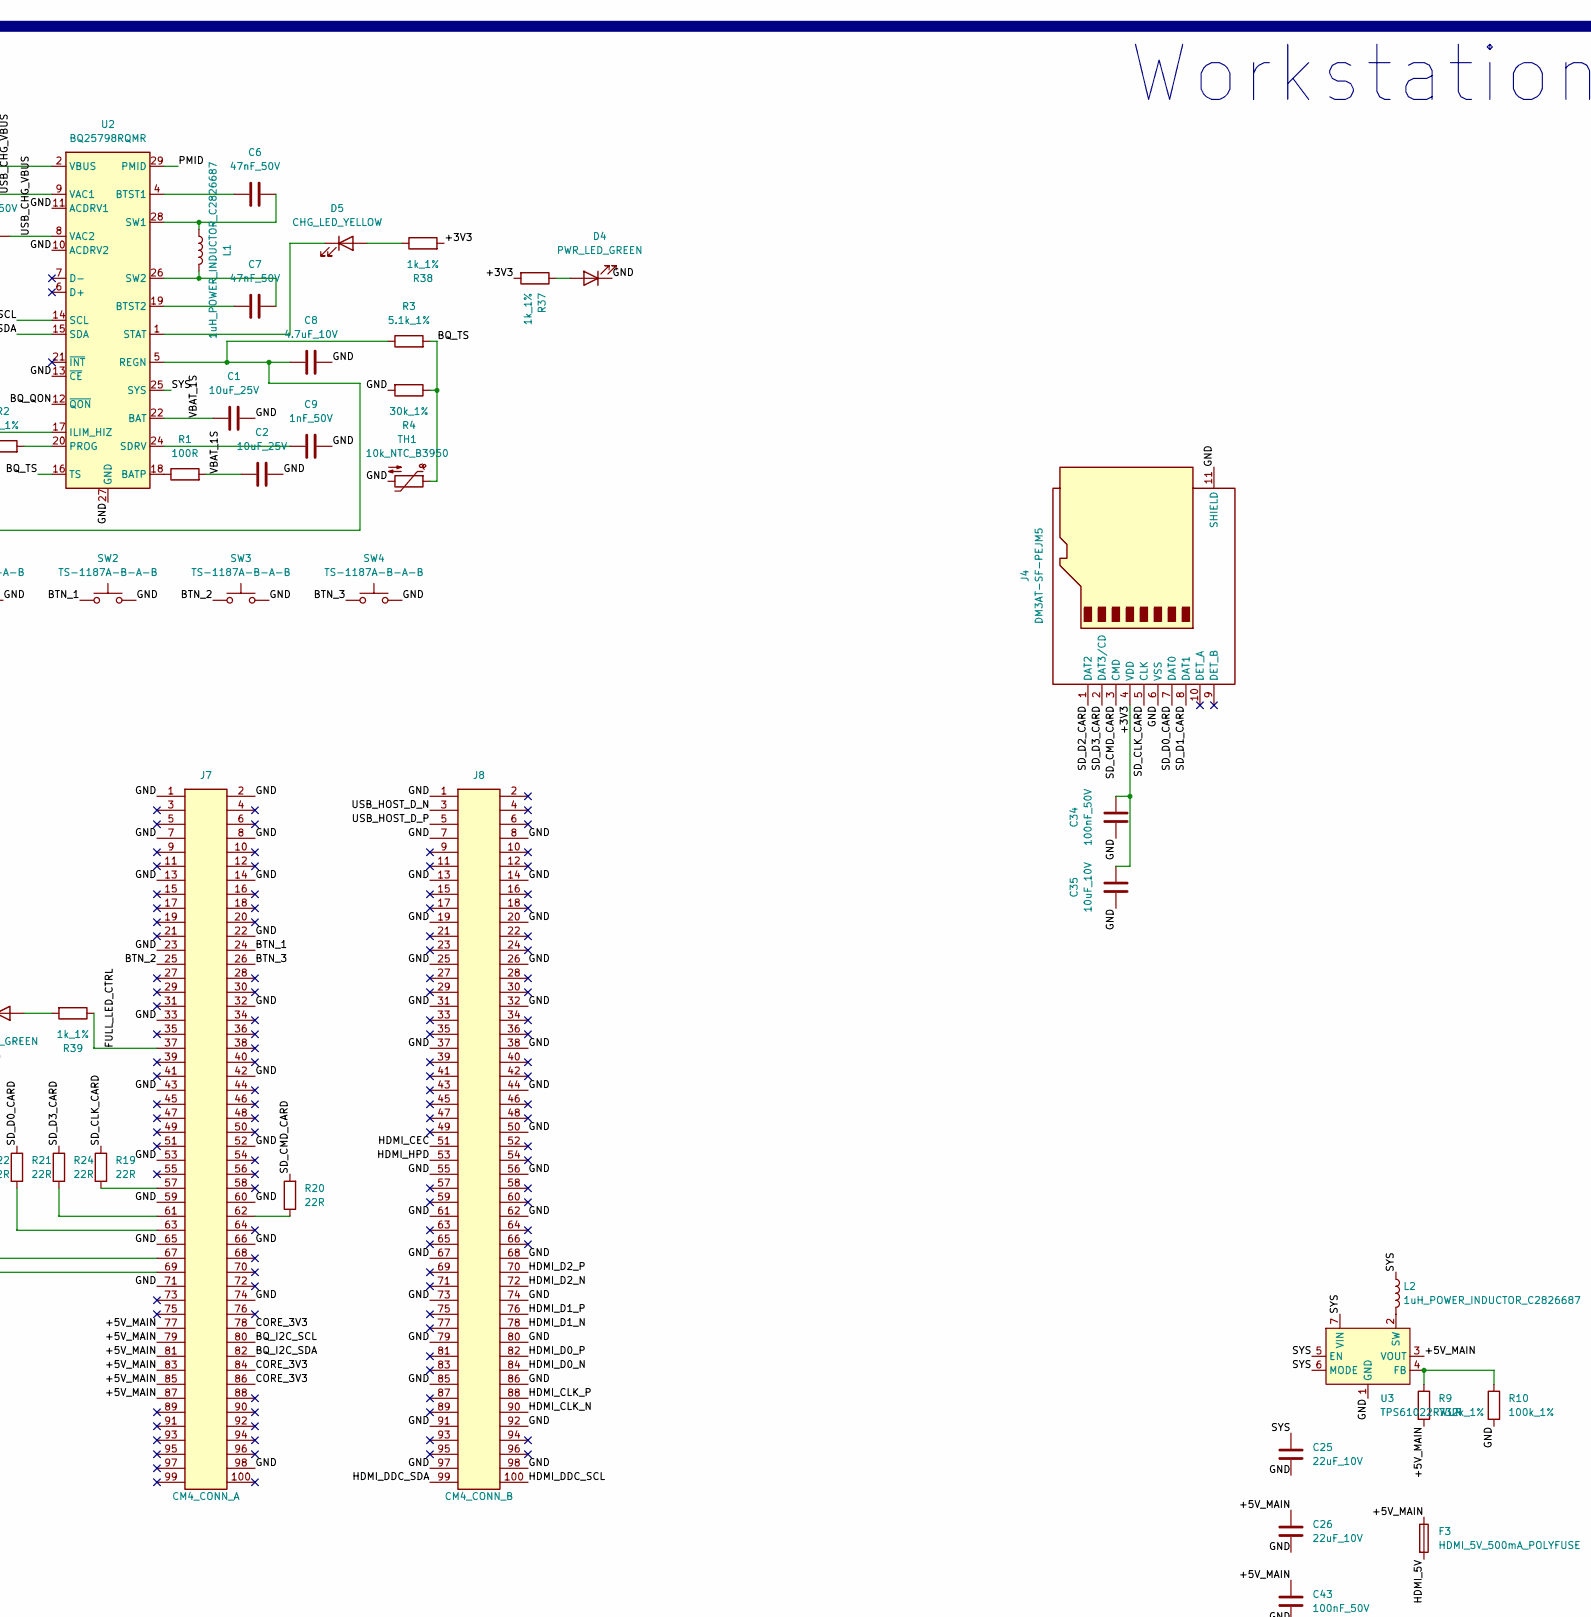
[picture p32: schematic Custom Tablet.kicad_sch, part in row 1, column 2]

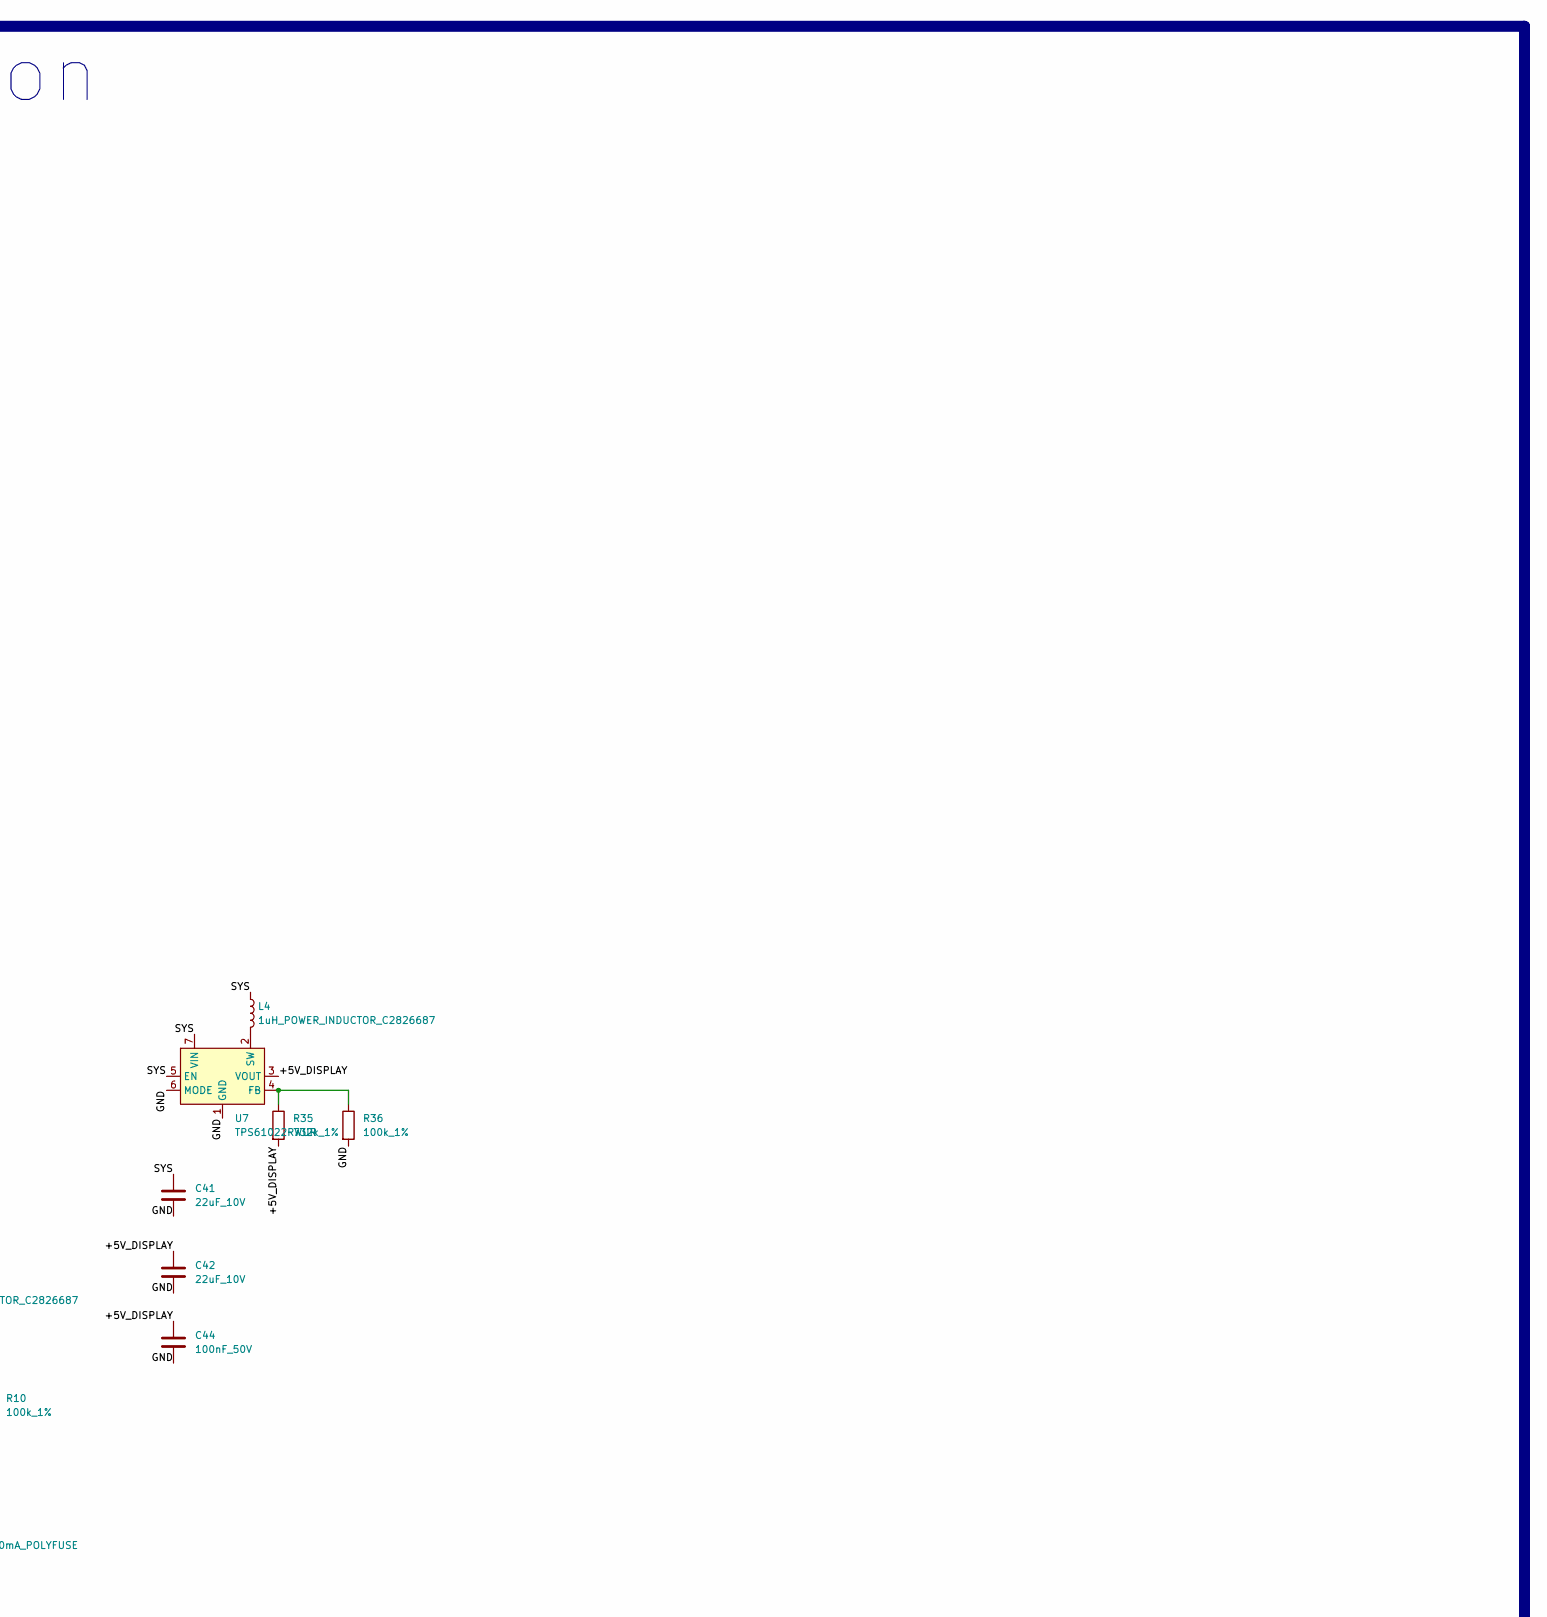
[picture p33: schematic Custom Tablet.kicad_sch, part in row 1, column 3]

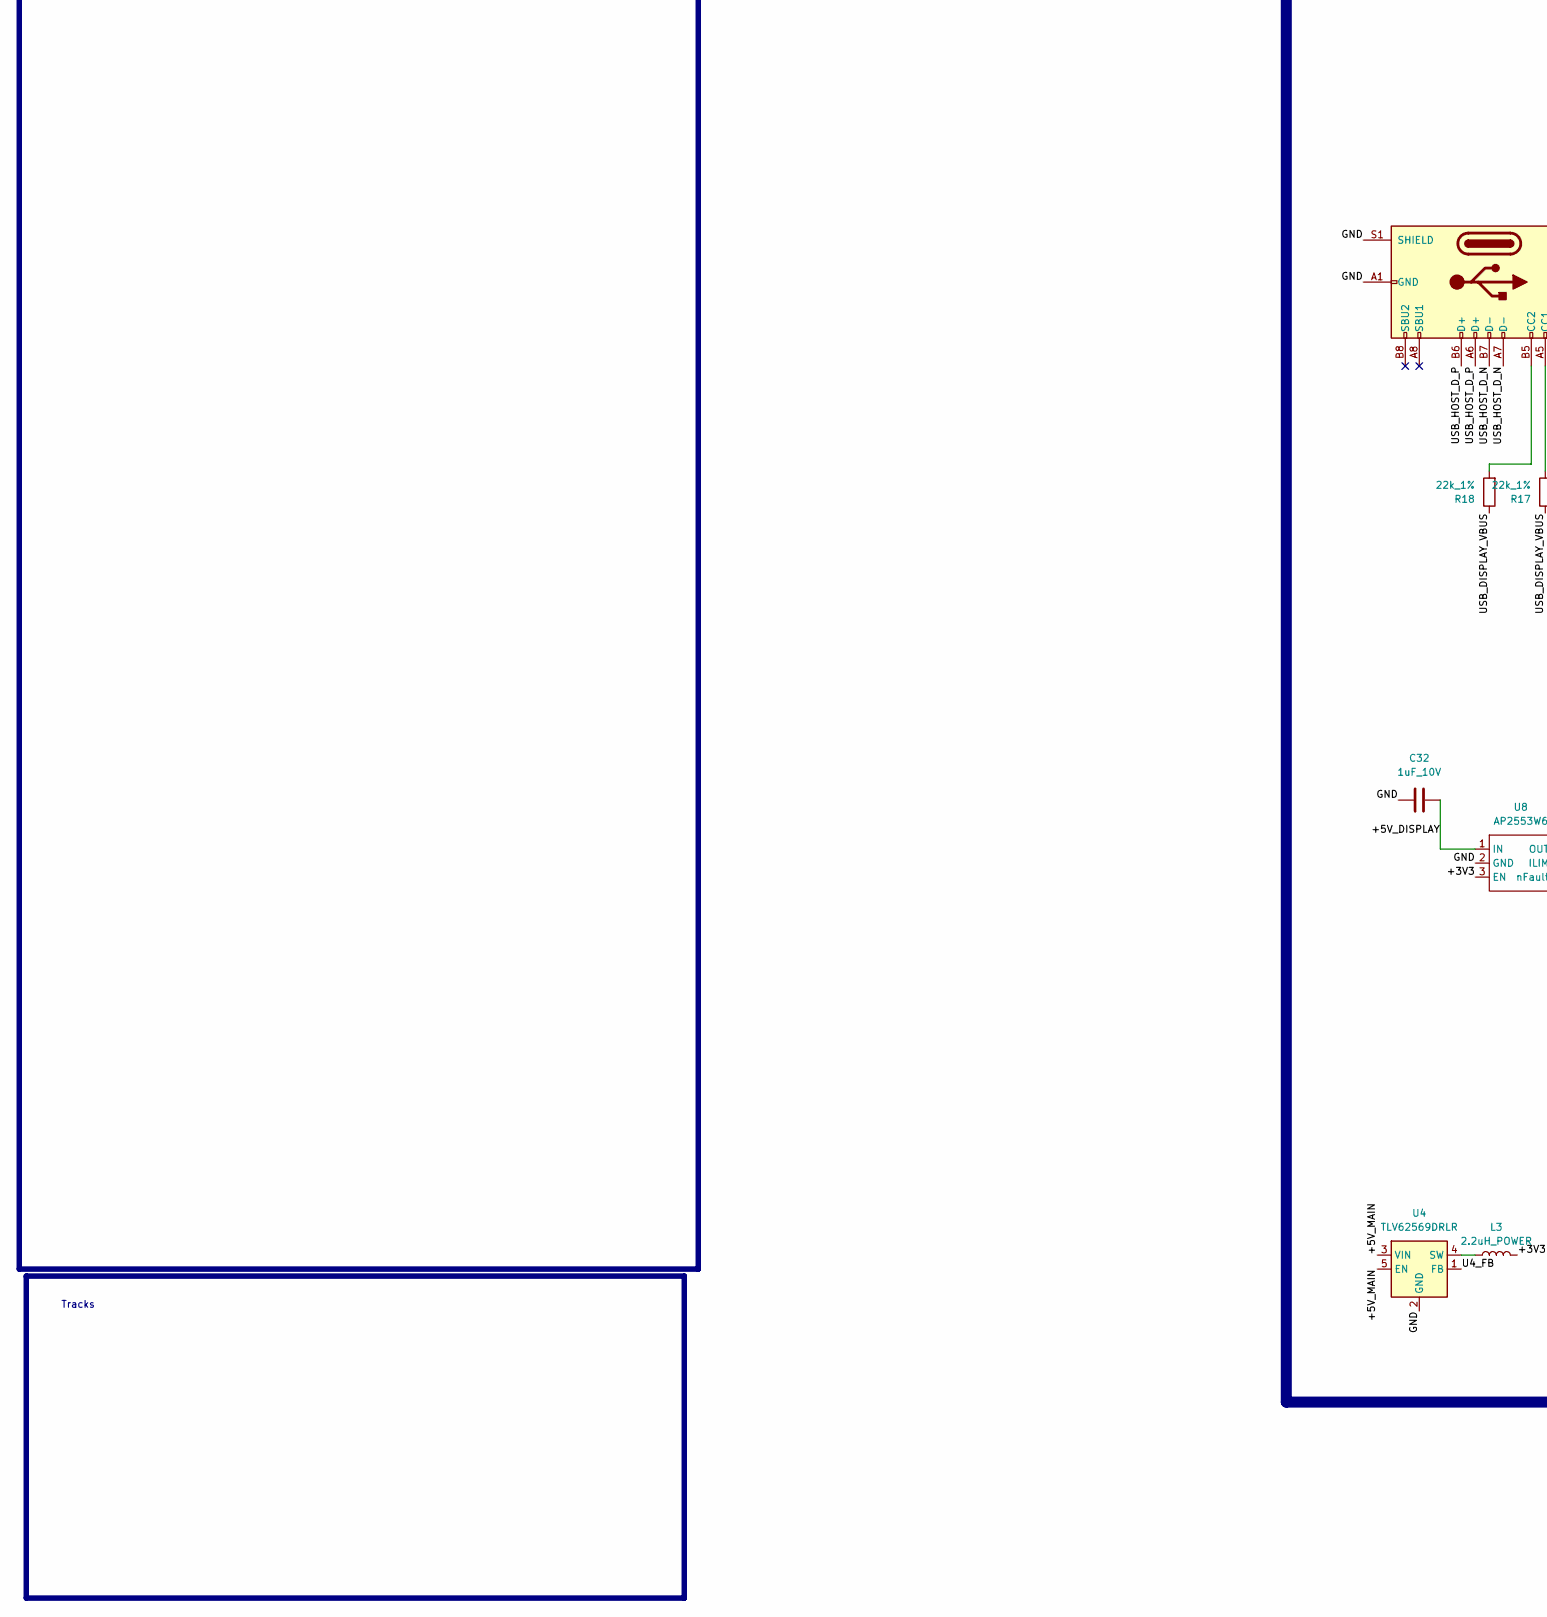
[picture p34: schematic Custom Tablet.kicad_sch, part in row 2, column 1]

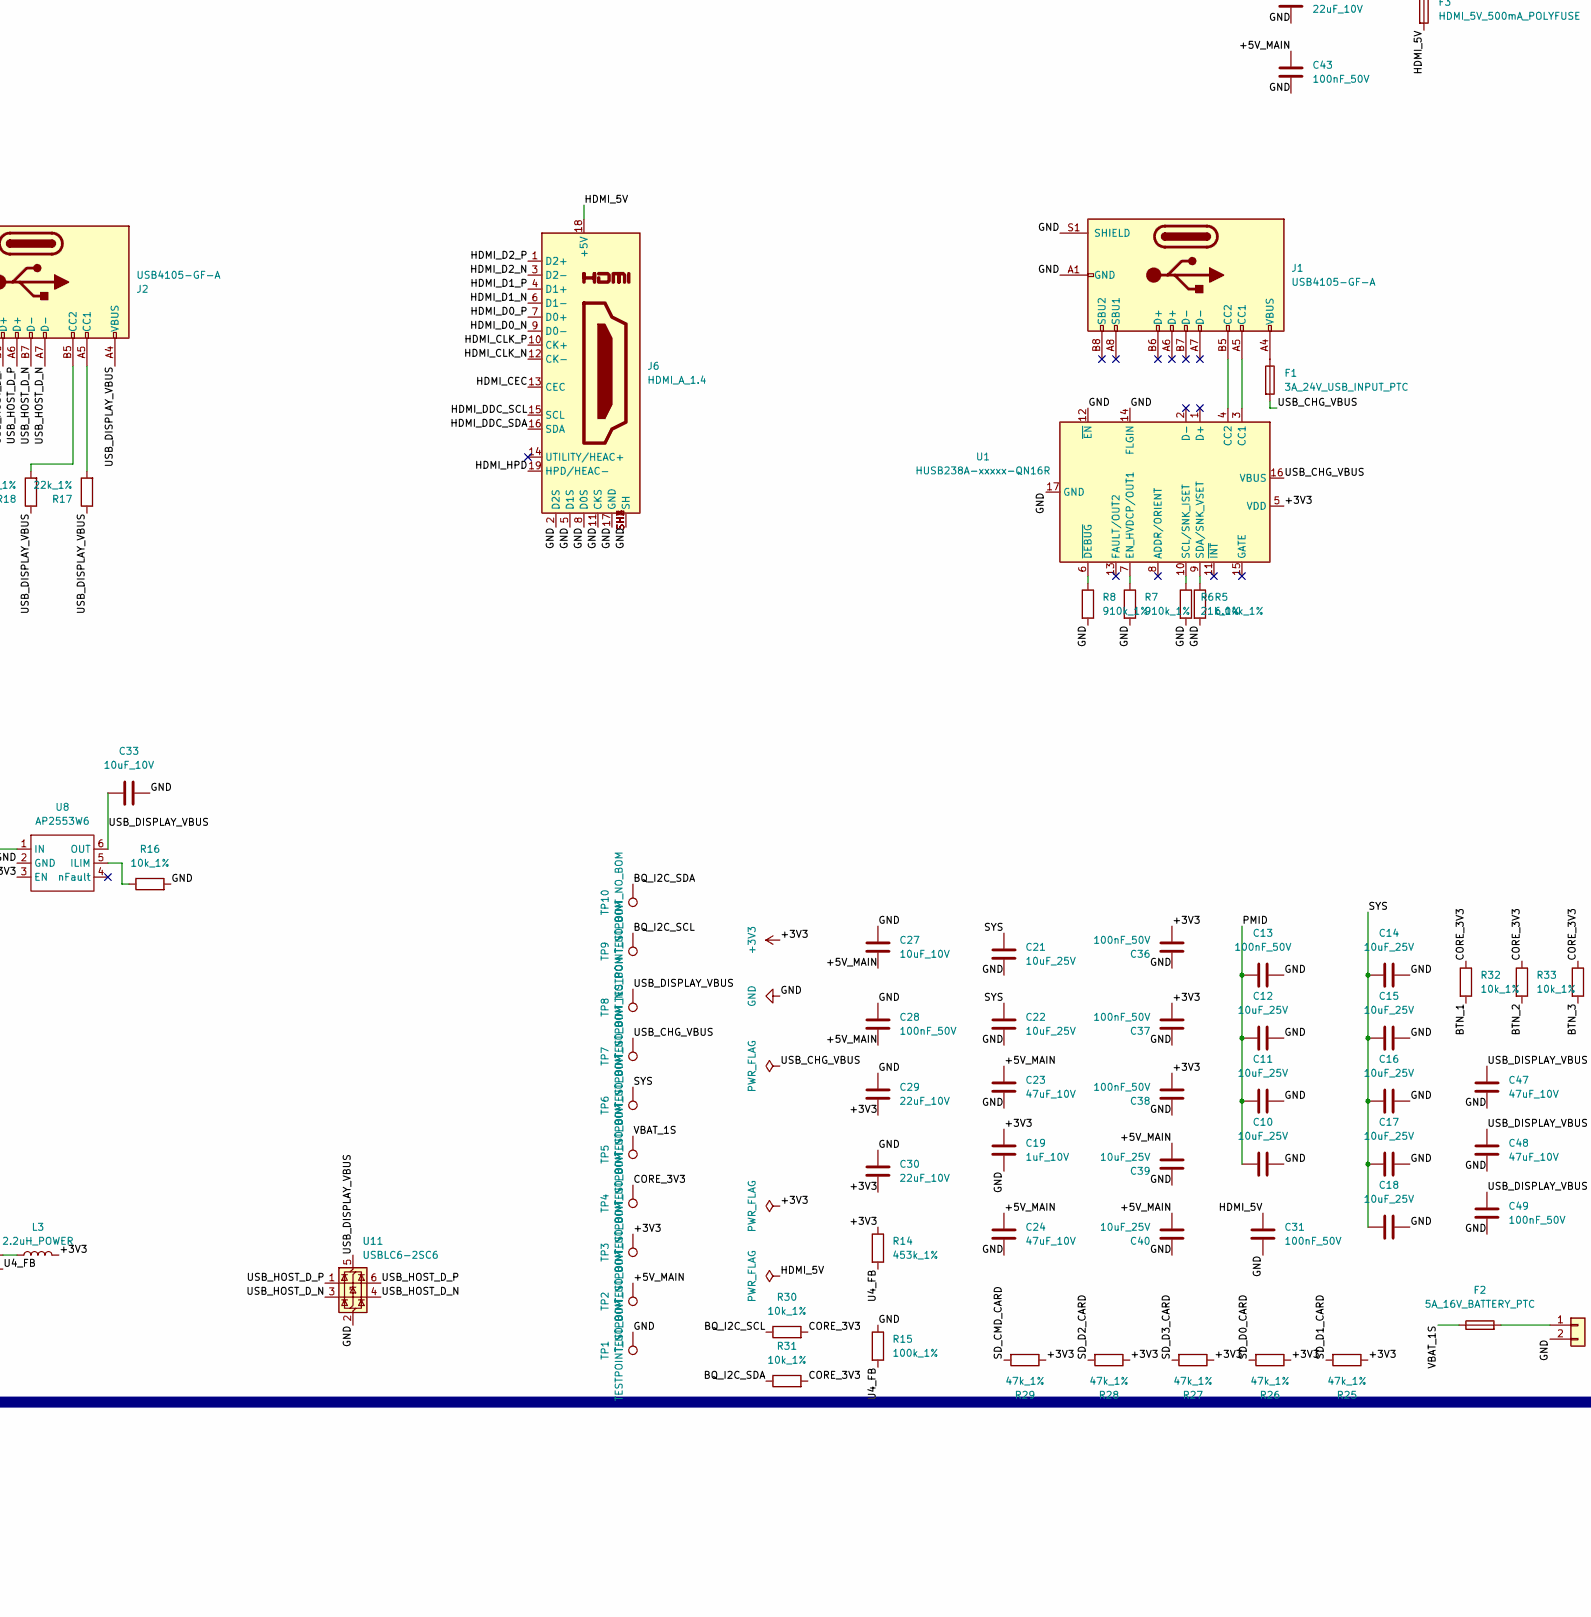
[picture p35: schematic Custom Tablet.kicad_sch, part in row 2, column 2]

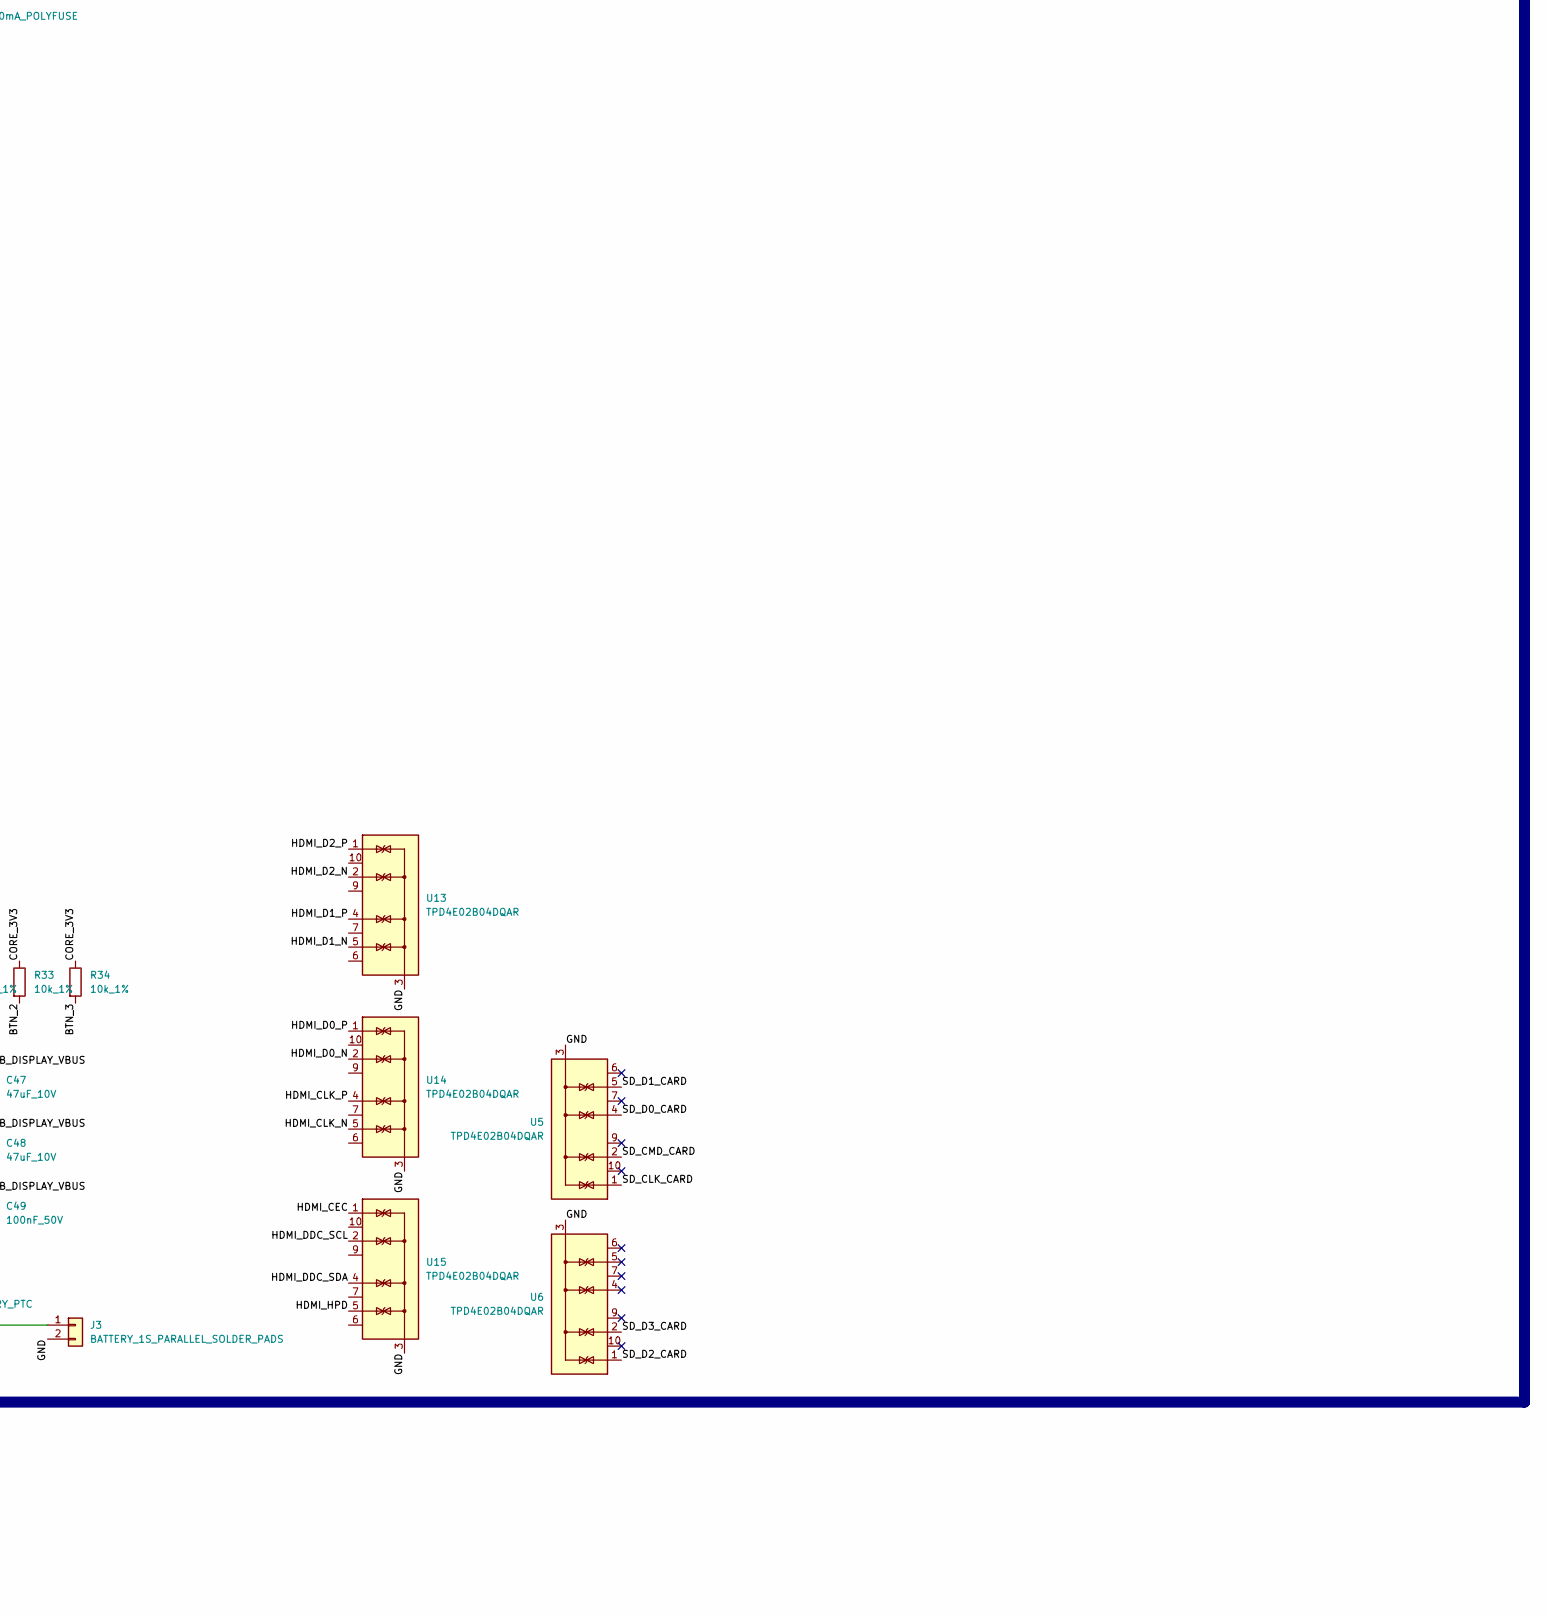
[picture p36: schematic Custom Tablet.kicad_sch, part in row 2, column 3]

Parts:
C1, C2, C3, C4, C10, C11, C12, C14, C15, C16, C17, C18, C21, C22, C39, C40: 10uF_25V; C_0805_2012Metric; MPN CL21A106KAYNNNE; LCSC C15850
C5, C13, C28, C31, C34, C36, C37, C38, C43, C44, C49: 100nF_50V; C_0603_1608Metric; MPN CC0603KRX7R9BB104; LCSC C14663
C6, C7: 47nF_50V; C_0603_1608Metric; MPN CL10B473KB8NNNC; LCSC C1622
C8: 4.7uF_10V; C_0603_1608Metric; MPN CL10A475KO8NNNC; LCSC C19666
C9: 1nF_50V; C_0603_1608Metric; MPN CL10B102KB8NNNC; LCSC C1588
C19, C32: 1uF_10V; C_0603_1608Metric; MPN CL10A105KB8NNNC; LCSC C15849
C23, C24, C47, C48: 47uF_10V; C_1210_3225Metric; MPN CL32A476KOJNNNE; LCSC C2932477
C25, C26, C29, C30, C41, C42: 22uF_10V; C_0805_2012Metric; MPN CL21A226MAQNNNE; LCSC C45783
C27, C33, C35: 10uF_10V; C_0805_2012Metric; MPN CL21A106KAYNNNE; LCSC C15850
D4: PWR_LED_GREEN; LED_0603_1608Metric; MPN XL-1608UGC-06A; LCSC C7371903
D5: CHG_LED_YELLOW; LED_0603_1608Metric; MPN XL-1608UYC-06; LCSC C965802
D6: FULL_LED_GREEN; LED_0603_1608Metric; MPN XL-1608UGC-06A; LCSC C7371903
F1: 3A_24V_USB_INPUT_PTC; Fuse_2920_7451Metric; MPN BSMD2920-300-24V; LCSC C2977527
F2: 5A_16V_BATTERY_PTC; Fuse_2920_7451Metric; MPN SMD2920P500TF/16; LCSC C108585
F3: HDMI_5V_500mA_POLYFUSE; Fuse_1206_3216Metric; MPN 1206L050/15YR; LCSC C151162
J1, J2: USB4105-GF-A; USB_C_Receptacle_GCT_USB4105-xx-A_16P_TopMnt_Horizontal; MPN USB4105-GF-A; LCSC C3020560
J3: BATTERY_1S_PARALLEL_SOLDER_PADS; SolderWire-0.5sqmm_1x02_P4.6mm_D0.9mm_OD2.1mm; MPN 1S parallel battery wire solder pads; LCSC N/A
J4: DM3AT-SF-PEJM5; microSD_HC_Hirose_DM3AT-SF-PEJM5; MPN DM3AT-SF-PEJM5; LCSC C114218
J6: HDMI_A_1.4; EDAC 690-019-298-412; MPN 690-019-298-412; LCSC C5291558
J7: CM4_CONN_A; Hirose_DF40C-100DS-0.4V_2x50_P0.4mm; MPN DF40C-100DS-0.4V(51); LCSC C597931
J8: CM4_CONN_B; Hirose_DF40C-100DS-0.4V_2x50_P0.4mm; MPN DF40C-100DS-0.4V(51); LCSC C597931
L1, L2, L4: 1uH_POWER_INDUCTOR_C2826687; L_Sumida_CR75; MPN CD75-1R0M; LCSC C2826687
L3: 2.2uH_POWER; L_Bourns-SRN4018; MPN SRN4018TA-2R2M; LCSC C2044386
R1: 100R; R_0603_1608Metric; MPN 0603 100R 1%; LCSC C22775
R2: 3k_1%; R_0603_1608Metric; MPN 0603WAF3001T5E; LCSC C4211
R3: 5.1k_1%; R_0603_1608Metric; MPN 5.1k 1% 0603; LCSC C23186
R4: 30k_1%; R_0603_1608Metric; MPN 0603WAF3002T5E; LCSC C22984
R5: 6.04k_1%; R_0603_1608Metric; MPN 0603WAF6041T5E; LCSC C25977
R6: 21k_1%; R_0603_1608Metric; MPN 0603WAF2102T5E; LCSC C22956
R7, R8: 910k_1%; R_0603_1608Metric; MPN RC0603FR-07910KL; LCSC C137672
R9, R35: 732k_1%; R_0603_1608Metric; MPN 0603WAF7323T5E; LCSC C23239
R10, R15, R36: 100k_1%; R_0603_1608Metric; MPN 0603WAF1003T5E; LCSC C25803
R14: 453k_1%; R_0603_1608Metric; MPN RC0603FR-07453KL; LCSC C273765
R16, R30, R31, R32, R33, R34: 10k_1%; R_0603_1608Metric; MPN 0603WAF1002T5E; LCSC C25804
R17, R18: 22k_1%; R_0603_1608Metric; MPN 0603WAF2202T5E; LCSC C31850
R19, R20, R21, R22, R23, R24: 22R; R_0603_1608Metric; MPN 0603WAF220JT5E; LCSC C23345
R25, R26, R27, R28, R29: 47k_1%; R_0603_1608Metric; MPN 0603WAF4702T5E; LCSC C25819
R37, R38, R39: 1k_1%; R_0603_1608Metric; MPN 0603WAF1001T5E; LCSC C21190
SW1, SW2, SW3, SW4: TS-1187A-B-A-B; SW_Push_1P1T_XKB_TS-1187A; MPN TS-1187A-B-A-B; LCSC C318884
TH1: 10k_NTC_B3950; R_0603_1608Metric; MPN 10k NTC B3950; LCSC C2892547
TP1, TP2, TP3, TP4, TP5, TP6, TP7, TP8, TP9, TP10: TESTPOINT_NO_BOM; TestPoint_Pad_D1.0mm; MPN N/A; LCSC N/A
U1: HUSB238A-xxxxx-QN16R; WQFN-16-1EP_3x3mm_P0.5mm_EP1.75x1.75mm; MPN HUSB238A-BB001-QN16R; LCSC C24833806
U2: BQ25798RQMR; Texas_RQM0029A_VQFN-29_4x4mm_P0.4mm; MPN BQ25798RQMR; LCSC C2876593
U3, U7: TPS61022RWUR; Texas_RWU0007A_VQFN-7_2x2mm_P0.5mm; MPN TPS61022RWUR; LCSC C915088
U4: TLV62569DRLR; SOT-563; MPN TLV62569DRLR; LCSC C163217
U5, U6, U13, U14, U15: TPD4E02B04DQAR; USON-10_2.5x1.0mm_P0.5mm; MPN TPD4E02B04DQAR; LCSC C106794
U8: AP2553W6; SOT-23-6; MPN AP2553W6-7; LCSC C212302
U11: USBLC6-2SC6; SOT-23-6; MPN USBLC6-2SC6; LCSC C7519

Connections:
+3V3: C19.1, C29.2, C30.2, C34.2, C35.2, C36.2, C37.2, C38.2, J4.4 (VDD), L3.2, R14.1, R25.1, R26.1, R27.1, R28.1, R29.1, R37.2, R38.2, TP3.1, U1.5 (VDD), U8.3 (EN)
/+5V_DISPLAY: C32.1, C42.1, C44.1, R35.2, U7.3 (VOUT), U8.1 (IN)
/+5V_MAIN: C23.1, C24.1, C26.1, C27.2, C28.2, C39.2, C40.2, C43.1, F3.1, J7.77, J7.79, J7.81, J7.83, J7.85, J7.87, R9.2, TP2.1, U3.3 (VOUT), U4.3 (VIN), U4.5 (EN)
/BQ_I2C_SCL: J7.80, R30.1, TP9.1, U2.14 (SCL)
/BQ_I2C_SDA: J7.82, R31.1, TP10.1, U2.15 (SDA)
/BQ_QON: SW1.1, U2.12 (~QON)
/BQ_TS: R3.2, R4.1, TH1.1, U2.16 (TS)
/BTN_1: J7.24, R32.2, SW2.1
/BTN_2: J7.25, R33.2, SW3.1
/BTN_3: J7.26, R34.2, SW4.1
/CORE_3V3: J7.78, J7.84, J7.86, R30.2, R31.2, R32.1, R33.1, R34.1, TP4.1
/FULL_LED_CTRL: J7.37, R39.1
/HDMI_5V: C31.1, F3.2, J6.18 (+5V)
/HDMI_CEC: J6.13 (CEC), J8.51, U15.1 (IO1)
/HDMI_CLK_N: J6.12 (CK-), J8.90, U14.5 (IO4), U14.6 (NC)
/HDMI_CLK_P: J6.10 (CK+), J8.88, U14.4 (IO3), U14.7 (NC)
/HDMI_D0_N: J6.9 (D0-), J8.84, U14.2 (IO2), U14.9 (NC)
/HDMI_D0_P: J6.7 (D0+), J8.82, U14.1 (IO1), U14.10 (NC)
/HDMI_D1_N: J6.6 (D1-), J8.78, U13.5 (IO4)
/HDMI_D1_P: J6.4 (D1+), J8.76, U13.4 (IO3)
/HDMI_D2_N: J6.3 (D2-), J8.72, U13.2 (IO2)
/HDMI_D2_P: J6.1 (D2+), J8.70, U13.1 (IO1)
/HDMI_DDC_SCL: J6.15 (SCL), J8.100, U15.2 (IO2)
/HDMI_DDC_SDA: J6.16 (SDA), J8.99, U15.4 (IO3)
/HDMI_HPD: J6.19 (HPD/HEAC-), J8.53, U15.5 (IO4)
/PMID: C10.1, C11.1, C12.1, C13.1, U2.29 (PMID)
/SD_CLK_CARD: J4.5 (CLK), R19.1, U5.1 (IO1)
/SD_CMD_CARD: J4.3 (CMD), R20.2, R29.2, U5.2 (IO2)
/SD_D0_CARD: J4.7 (DAT0), R21.1, R26.2, U5.4 (IO3)
/SD_D1_CARD: J4.8 (DAT1), R22.1, R25.2, U5.5 (IO4)
/SD_D2_CARD: J4.1 (DAT2), R23.1, R28.2, U6.1 (IO1)
/SD_D3_CARD: J4.2 (DAT3/CD), R24.1, R27.2, U6.2 (IO2)
/U4_FB: R14.2, R15.2, U4.1 (FB)
/USB_CHG_VBUS: C3.2, C4.2, C5.2, F1.2, TP7.1, U1.16 (VBUS), U2.2 (VBUS), U2.3 (VBUS), U2.8 (VAC2), U2.9 (VAC1)
/USB_DISPLAY_VBUS: C33.1, C47.1, C48.1, C49.1, J2.A4 (VBUS), J2.A9 (VBUS), J2.B4 (VBUS), J2.B9 (VBUS), R17.1, R18.1, TP8.1, U8.6 (OUT), U11.5 (VBUS)
/USB_HOST_D_N: J2.A7 (D-), J2.B7 (D-), J8.3, U11.3 (I/O2), U11.4 (I/O2)
/USB_HOST_D_P: J2.A6 (D+), J2.B6 (D+), J8.5, U11.1 (I/O1), U11.6 (I/O1)
/VBAT_1S: C1.1, C2.1, F2.1, R1.2, TP5.1, U2.22 (BAT), U2.23 (BAT)
unnamed: D4.2 (A), R37.1
unnamed: D5.2 (A), R38.1
unnamed: D5.1 (K), U2.1 (STAT)
unnamed: D6.2 (A), R39.2
unnamed: F1.1, J1.A4 (VBUS), J1.A9 (VBUS), J1.B4 (VBUS), J1.B9 (VBUS)
unnamed: J1.A5 (CC1), U1.3 (CC1)
unnamed: J1.B5 (CC2), U1.4 (CC2)
unnamed: J2.A5 (CC1), R17.2
unnamed: J2.B5 (CC2), R18.2
unnamed: F2.2, J3.1
unnamed: J7.57, R19.2
unnamed: J7.61, R24.2
unnamed: J7.62, R20.1
unnamed: J7.63, R21.2
unnamed: J7.67, R22.2
unnamed: J7.69, R23.2
unnamed: R7.1, U1.7 (EN_HVDCP/OUT1)
unnamed: R6.1, U1.10 (SCL/SNK_ISET)
unnamed: R5.1, U1.9 (SDA/SNK_VSET)
unnamed: R8.1, U1.6 (~DEBUG)
unnamed: R1.1, U2.18 (BATP)
unnamed: C6.1, U2.4 (BTST1)
unnamed: C7.1, U2.19 (BTST2)
unnamed: C8.1, R3.1, U2.5 (REGN), U2.17 (ILIM_HIZ)
unnamed: R2.2, U2.20 (PROG)
unnamed: C9.1, U2.24 (SDRV)
unnamed: C6.2, L1.1, U2.28 (SW1)
unnamed: C7.2, L1.2, U2.26 (SW2)
unnamed: R9.1, R10.1, U3.4 (FB)
unnamed: L2.2, U3.2 (SW)
unnamed: L3.1, U4.4 (SW)
unnamed: R35.1, R36.1, U7.4 (FB)
unnamed: L4.2, U7.2 (SW)
unnamed: R16.1, U8.5 (ILIM)

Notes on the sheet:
Battery related stuff
Other
Workstation
Tracks
Display related stuff
USB related stuff

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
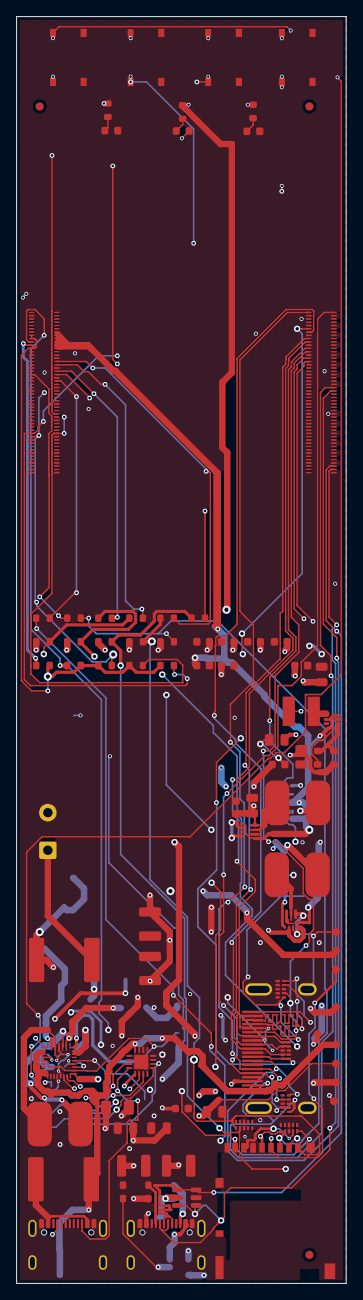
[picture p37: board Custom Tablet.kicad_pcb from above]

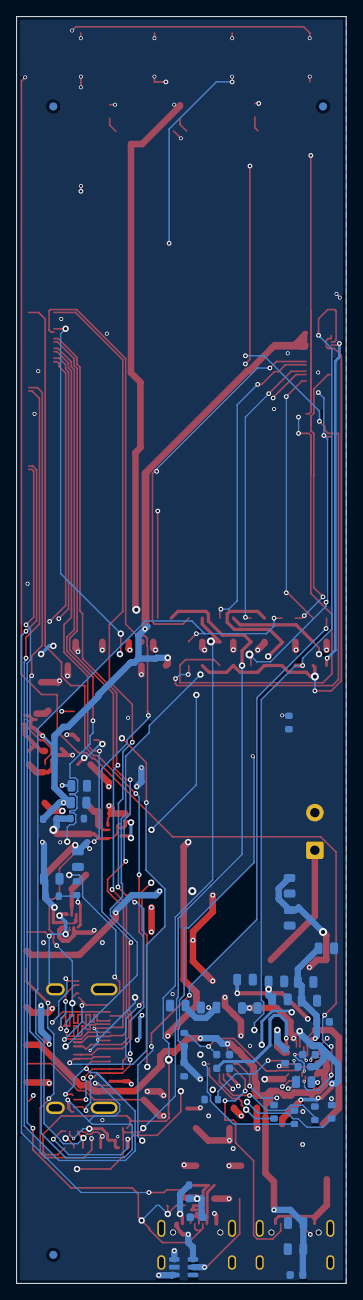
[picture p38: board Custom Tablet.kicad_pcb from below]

Board: 4 copper layers, 40.3 x 155.0 mm, 131 parts (43 on the bottom side), 74 nets.

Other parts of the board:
JLC_FID_BOT_1, JLC_FID_BOT_2, JLC_FID_BOT_3: JLC_GLOBAL_FIDUCIAL; Fiducial_1mm_Mask2mm
JLC_FID_TOP_1, JLC_FID_TOP_2, JLC_FID_TOP_3: JLC_GLOBAL_FIDUCIAL; Fiducial_1mm_Mask2mm

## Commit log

2026-07-28 Add files via upload
    PCB Files
    [Custom Tablet.kicad_pcb, Custom Tablet.kicad_sch]
2026-07-28 Add files via upload
    Assembly Files
    [Custom Tablet-B_Cu.gbr, Custom Tablet-B_Mask.gbr, Custom Tablet-B_Paste.gbr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]
2026-07-28 Add files via upload
    CAD Files
    [Tablet Project Assembly.f3z, Tablet Project Assembly.step, Tablet Project_Bottom Case.f3d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]
2026-07-29 Add files via upload
    Schematic Assets
